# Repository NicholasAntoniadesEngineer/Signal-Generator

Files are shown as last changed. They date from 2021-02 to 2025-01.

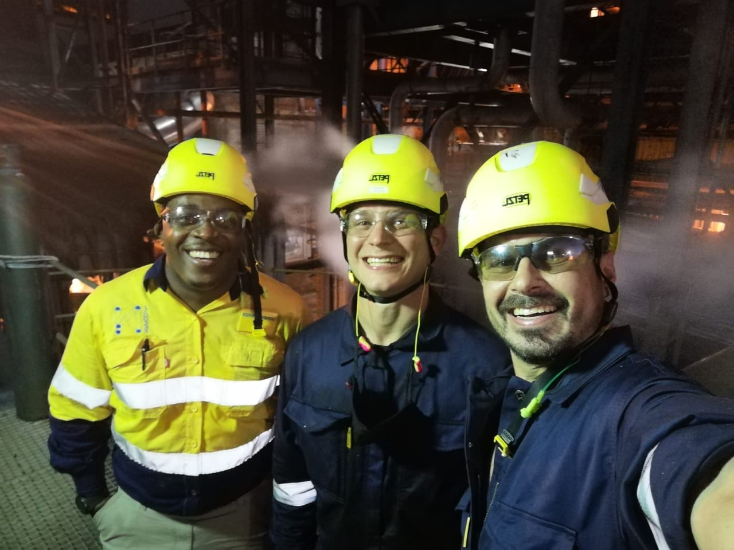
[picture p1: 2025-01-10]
pictures_and_videos/pictures/Installation crew 1.jpg

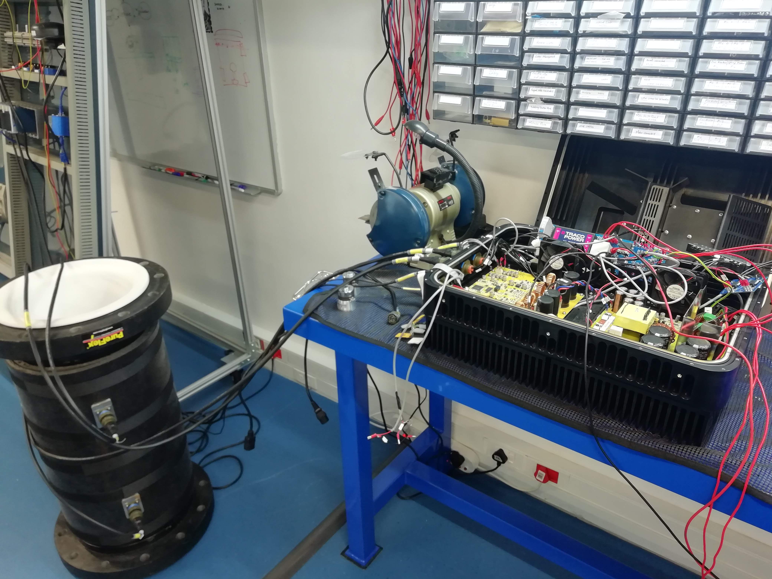
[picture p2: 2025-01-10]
pictures_and_videos/pictures/System Test.jpg

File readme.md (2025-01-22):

# Arbitrary Waveform Magnetic Field Generator (2020)

## Project Overview

This project focuses on developing an Arbitrary Waveform Generator (AWG) that allows the control of input signal frequency and amplitude through digital logic, interfacing with a CRIO (Compact Reconfigurable Input/Output) system. The system is designed to output a signal within the range of -2V to 2V peak-to-peak and supports a frequency range of 0-20kHz. The AWG is programmable via TTL or other logic interfaces.

This signal is then amplified and fed into a large coil to generate a magnetic field at the desired frequency and intensity.

## Industrial Application: Electromagnetic Scale Prevention

### Overview
The Arbitrary Waveform Generator was successfully deployed in an industrial sugar processing plant to combat scale formation in pipework. The system was integrated with a high-power amplifier to drive electromagnetic coils wrapped around critical pipe sections, implementing an innovative non-chemical scale prevention solution.

### System Configuration
- **Amplification Stage**: The AWG's output feeds into a high-power amplifier capable of driving large inductive loads
- **Electromagnetic Coils**: Custom-designed solenoid coils wrapped around pipe sections
- **Frequency Range**: Optimized to operate between 1-15 kHz for maximum effectiveness
- **Signal Characteristics**: Programmable waveforms with controlled frequency sweeps to target various mineral compositions

### Working Principle
The system generates precisely controlled electromagnetic fields that influence the crystallization process of scale-forming minerals. By affecting nucleation sites within the fluid

## Features

- **STM32 Microcontroller**: Implements the waveform generation using Direct Digital Synthesis (DDS).
- **Real-Time Operating System (RTOS)**: Ensures deterministic behavior for time-sensitive applications.
- **Programmable**: Supports control over frequency and amplitude via digital logic interfaces such as TTL.
- **Power Supply**: Operates with a wide input range and provides regulated outputs for the system.

## Waveform Generation Calculations

The AWG frequency generation is controlled through the following equations:

### 1. Prescaler (PSC):
PSC = ((Fclock / Ns) / (Fsine * (Period + 1))) - 1

Where:
- `Fclock` is the system clock frequency.
- `Ns` is the number of samples.
- `Fsine` is the desired sine wave frequency.
- `Period` is the period of the waveform.

### 2. Sine Wave Frequency (Fsine):
Fsine = (Fclock / Ns) / ((Period + 1) * (PSC + 1))

### Example Calculation:
Given the following values:
- `Fclock = 90MHz`
- `Ns = 100`
- `Period = 5`
- `PSC = 10`

You can calculate the sine wave frequency (`Fsine`) as:
Fsine = (90MHz / 100) / ((5 + 1) * (10 + 1)) = 13.636 kHz

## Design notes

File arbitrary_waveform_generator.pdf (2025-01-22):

# Arbitrary Waveform Generator

Nicholas Antoniades
2020

Table of Contents

1. (https://docs.google.com/document/d/1us7GVwpmYYnVgKDSI4ocPkmrK4ELYAW_x_JeFMqL49g/edit) Requirements
2. Design
3. PCB Configuration
4. Power Supply Validation
5. System Programming
6. System Test
7. Research

### Requirements

Attempting to find a black box solution that will allow the CRIO to control the input signal frequency and amplitude through some digital logic.

System Requirements:

1. An output achieving at least a -2V to 2V peak to peak output signal.
2. 0-20kHz frequency range.
3. Programmable via TTL or other logic.

PCB Requirements:

- USB DFU
- Power swich
- Level shifting circuitry
- DIP switch for boot mode settings
- DIP switch between power section and rest of circuit
- Power supply for +-5V
- Fuses
- Reset buttons
- LEDs
- ESD protection
- Reverse polarity protection
- SW with trace for debugging
- Temp sensor
- MAX485for RS485

### Design

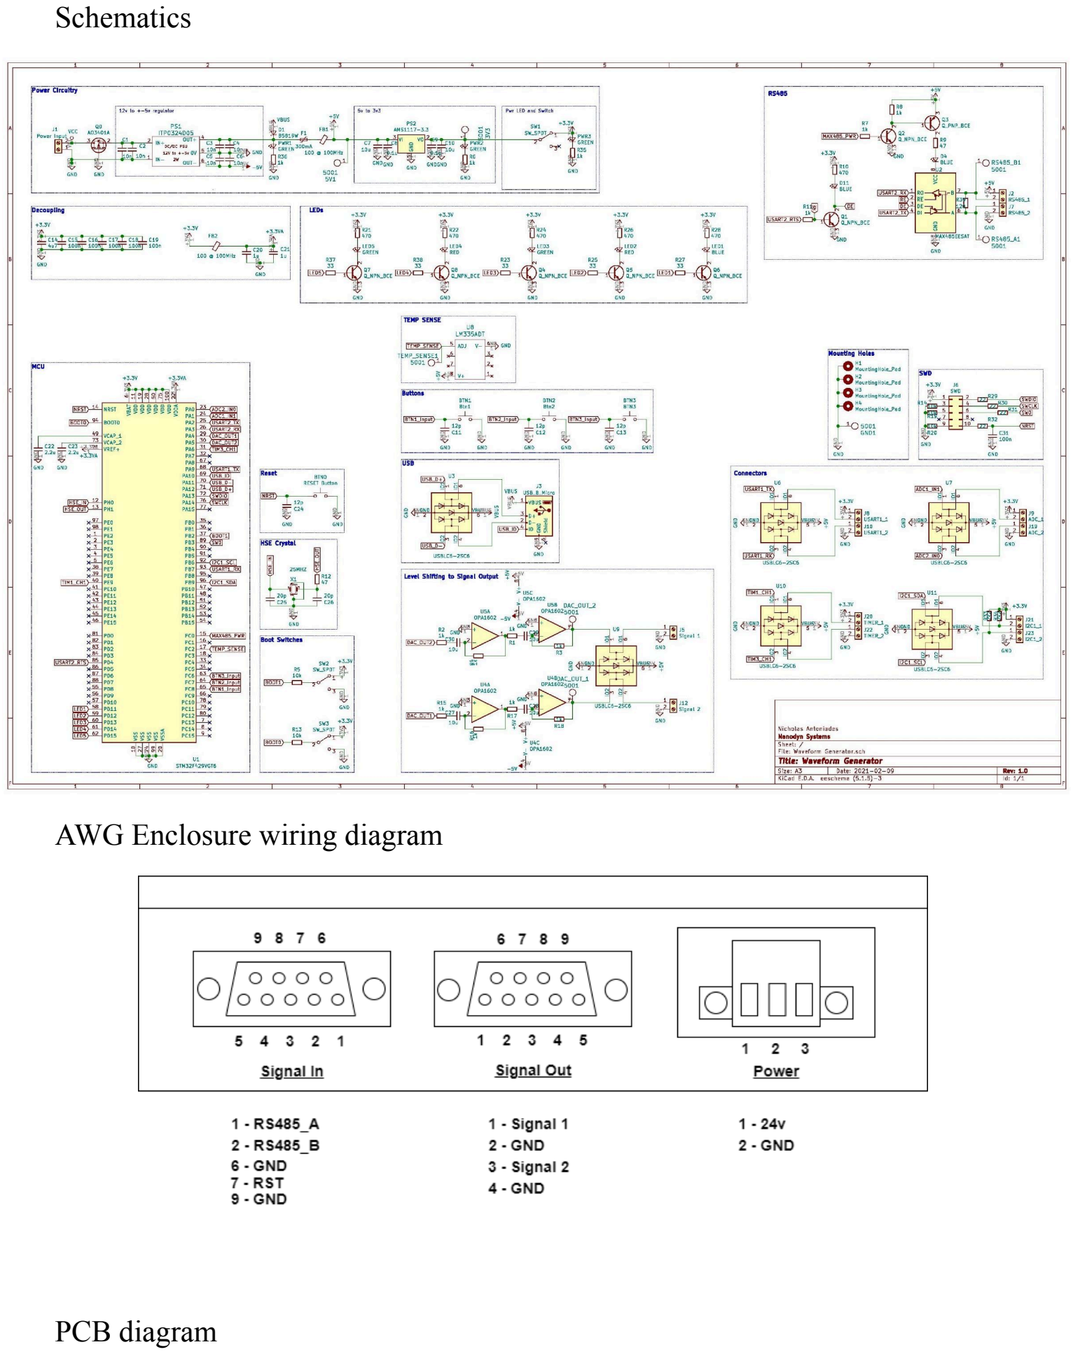
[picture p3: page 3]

Schematics

AWG Enclosure wiring diagram

PCB diagram

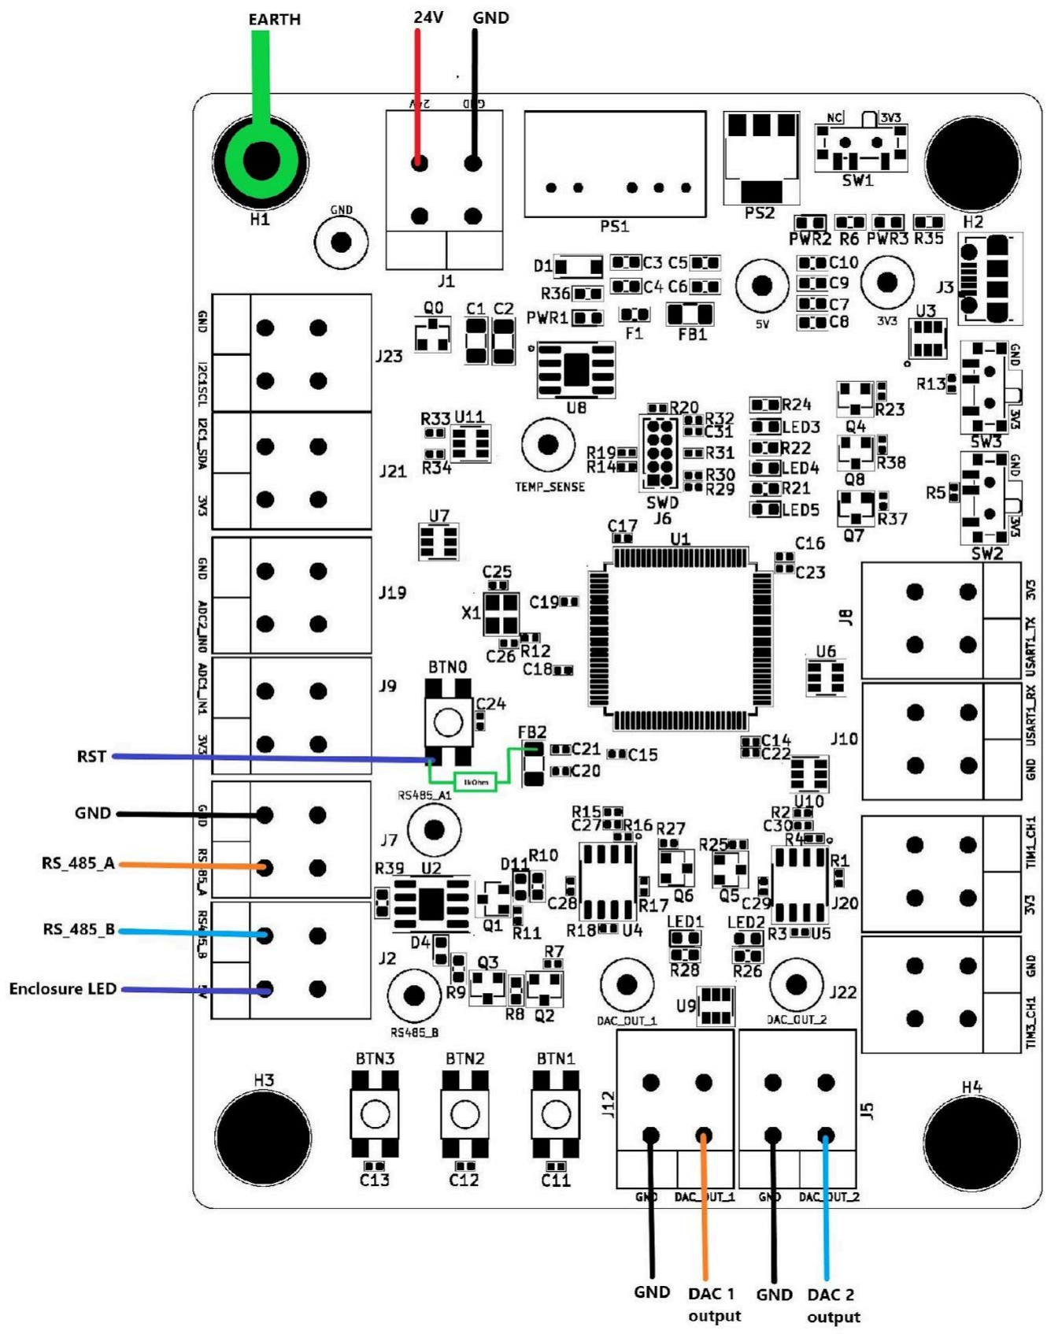
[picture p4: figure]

### PCB Configuration

Steps for setting up the PCB:

1. Add Fuse F1
2. Solder pull up resistor to NRST
3. Remove ESD protection U9. Bridge tracks as indicated
4. 10kOhm resistor was added as a pull-up resistor to bring the NRST pin to 3.3v
5. Removing LED D4 and bridging the pads as the voltage drop over the LED is such that the voltage over the MAX485 chip is too low.
6. Removing transistor Q1 and bridging its pads 1 and 2, then removing LED D11. This is so that DE and RE can be set at the same value. The original logic was so that they would be opposite values.
The 10kOhm pull-up resistor added can be seen in the figure below.
The ESD protection after the Op-Amp circuits were removed as the diode to the ground was clamping the circuit. Seen in the image below.
The inverting logic gate (The Npn diode) that was used to set the – pin and – pin which sets the MAX485 into transmit or receive mode was removed. This logic is not necessary as the pin is inverted already so both pins receive the same logic to switch between transmission and reception mode.

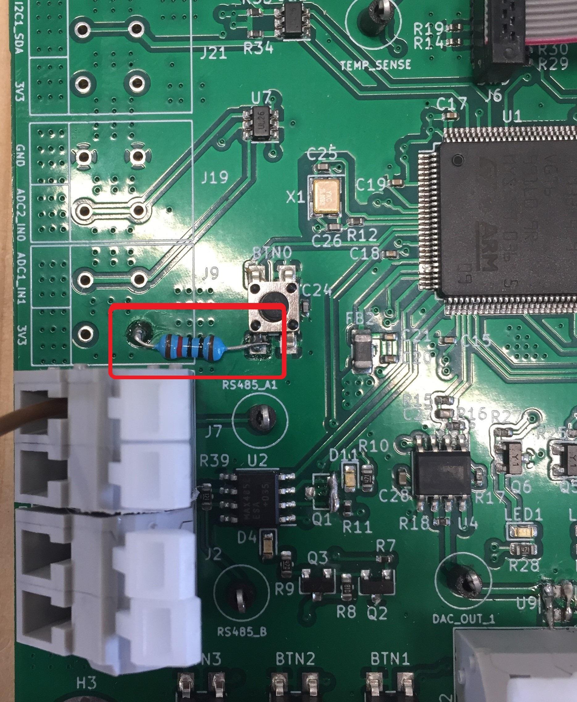
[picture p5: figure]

### Power supply validation

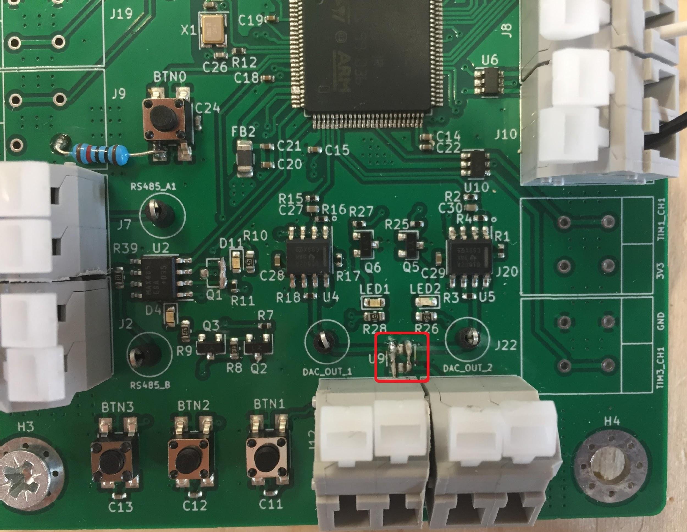
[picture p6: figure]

A 24V supply was connected to the 9V - 36V Input. +-5v and 3.3v were measured at the correct locations and STM MCU started up correctly and began to run the code.

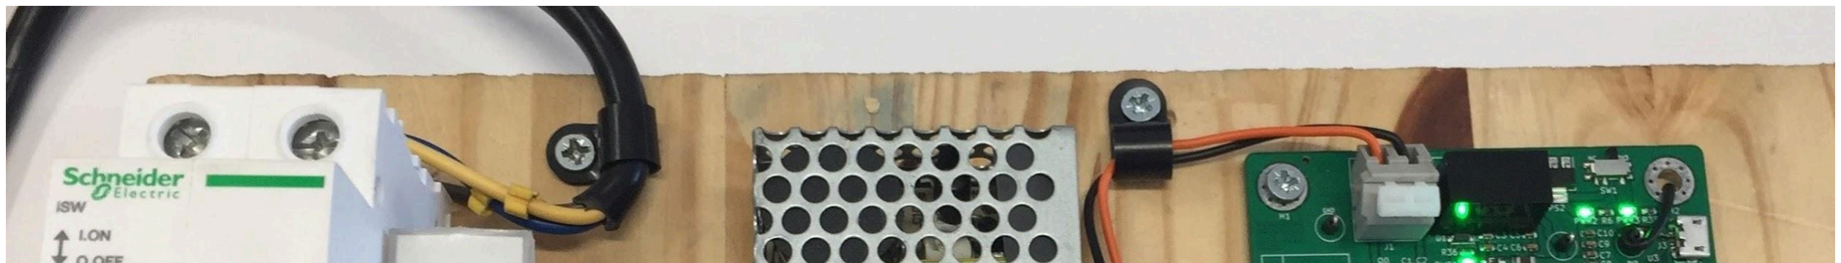
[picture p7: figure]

### System Programming

UART Programming of the AWG

The AWG was first programmed via the USB to serial interface
1. An external wire was soldered to a USB ID pin to access PA10
2. Boot0 switch(sw3) was set to 3v3 and the device was reset to enter bootloading mode.
3. Start STM32CubeProgrammer and select UART programming
4. Select erasing & programming.
5. Select the .elf file to be uploaded, this can be found in the Debug folder of the build files from the STM32CubeIDE.

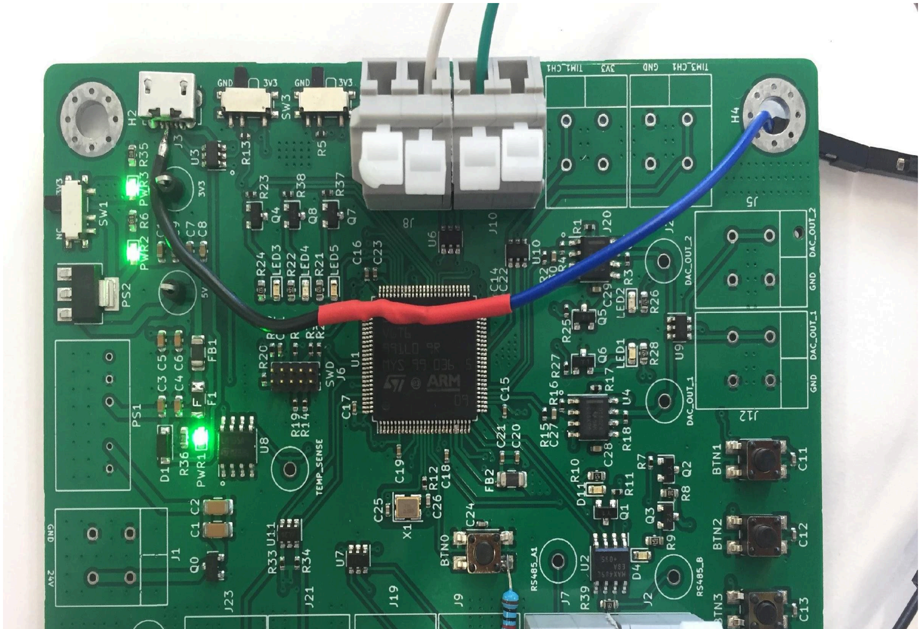
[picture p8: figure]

ST-Link V2 Programming of the AWG

1. Connect debugger and AWG PCB using the connector as seen in the figure below.
– | The footprint for the debugger on the AWG PCB is incorrect and inverted therefore the connector had to be manually wired to the correct orientation.
– | Add an extra wire from the ground of the debugger to the ground of the AWG PCB. Not seen in this image
2. Start STM32CubeProgrammer and select ST-Link programming
3. Select erasing & programming.
4. Select the .elf file to be uploaded, this can be found in the Debug folder of the build files from the STM32CubeIDE.

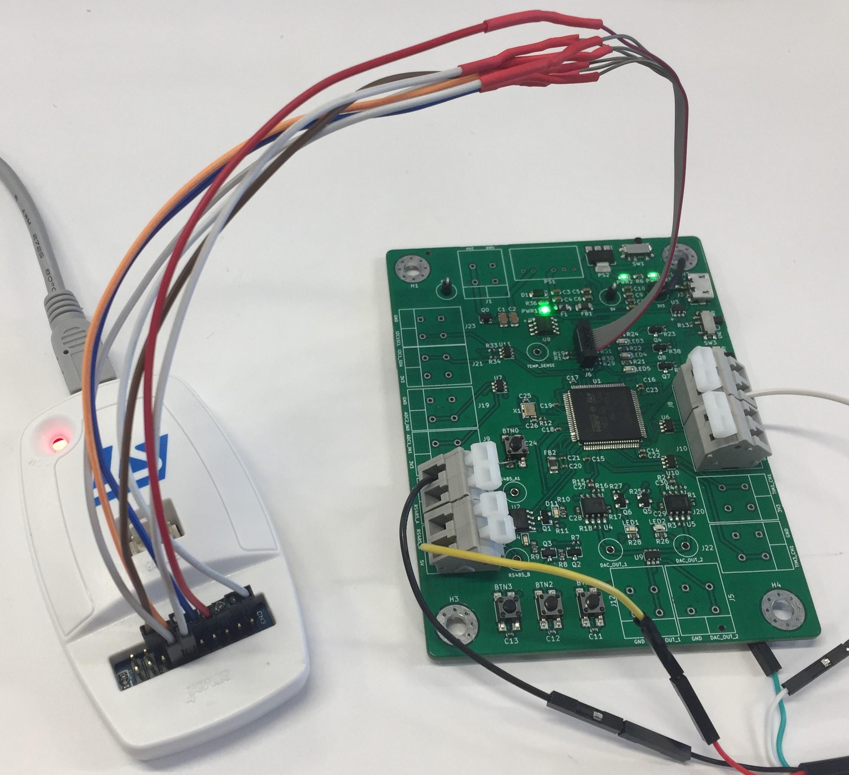
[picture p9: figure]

### System Test

The max output frequency is dependent on Ns, the number of samples that form one full period of the sine wave. For lower output frequencies a higher Ns can be used to increase the resolution of the signal. The following table indicates the appropriate ns value for a desired output frequency range. These are based on the STM32F429VGT6 used on the AWG. Based on the calculation:
PSC = - 1
There should be a function in the code that takes in the desired frequency and selects the appropriate Ns.
Other requirements for AWG:
1. The output signal must be scaled by o.5.
2. The output signal must be offset by 500.
3. DAC resolution = 4096
4. Fclock = 90 MHz
5. Period = 1.
6. PSC > 50

Setting up the RS485

1. Work on the correct response for uart
2. Set the MAX485 chip on

Waveform Generation Calculations:
PSC = - 1, Fsine = - 1, Fsine = = 13.636 kHz

Notes:
- When using op-amps it is important to consider the frequency limitations caused by the limited slew rate and bandwidth.
- Managing to get a working sine wave in the range of 0Hz and +- 50kHz.

### Research

Waveform Generation Calculations:

PSC = - 1, Fsine = - 1, Fsine = = 13.636 kHz
Notes:
- When using op-amps it is important to consider the frequency limitations caused by the limited slew rate and bandwidth.
- Managing to get a working sine wave in the range of 0Hz and +- 50kHz.
STM32 Nucleo 144 SWD Pinout
Using this pinout proved difficult and I was not able to programme the development board this way.

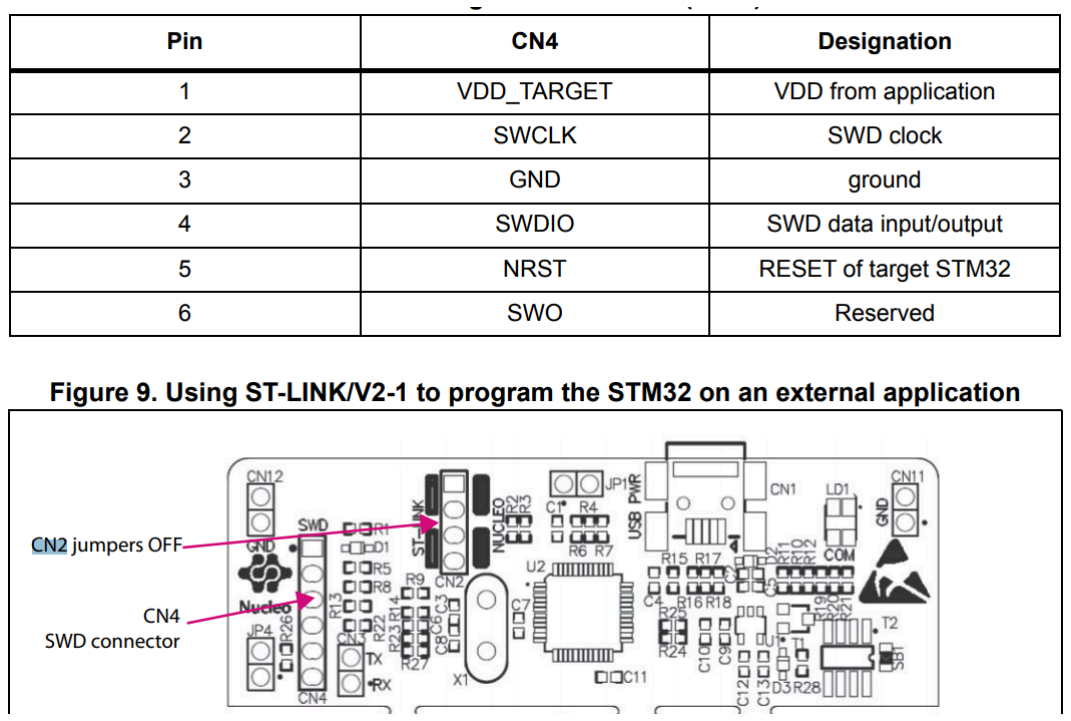
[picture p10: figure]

UART bootloader

Boot pin configurations: Refer to the chip reference manual for the correct configuration of pins Boot0 and Boot1 to put the device into the desired bootloader mode. For the STM32F439VGT6 the following pin configurations set the desired memory location to refer to for the boot mode.
USART bootloader protocol: Refer to AN2026 to activate the specific peripheral bootloader pins and settings. For the USART1 bootloader protocol commands and process refer to AN3155.
All communication from the programming tool to the device is verified by:
1. Checksum: received blocks of data bytes are XOR-ed. A byte containing the computed XOR of all previous bytes is added to the end of each communication (checksum byte). By XOR-ing all received bytes, data plus checksum, the result at the end of the packet must be 0x00.
2. For each command, the host sends a byte and its complement (XOR = 0x00).
3. UART: 1 start bit, even parity and 1 stop bit.
4. Each packet is either accepted (ACK answer) or discarded (NACK answer):
– | ACK = 0x79
– | NACK = 0x1F
UART message protocol

8 bytes message structure:
|<|(60/3C) : Start of message byte. |ADDR|() : Device Address byte. |CMD|() : Command byte. |DATA1| : Data byte 1. |DATA2| : Data byte 2. |DATA3| : Data byte 3. |DATA4| : Data byte 4. |>|(62/3E) : End of message byte.
List of commands from CRIO to STM:
1. On/off command.
2. Change - the frequency of DAC channel 1.
3. Change - the frequency of DAC channel 2.
4. Change - the amplitude of DAC channel 1.
5. Change - the amplitude of DAC channel 2.
6. Request - Voltage and Current measurement of channel 1 output.
7. Request - Voltage and Current measurement of channel 2 output.
8. Request - Temperature sensor 1 and 2 output.
9. Acknowledge message received.
10. Bad message received.
11. Request current system state.
List of messages from STM to CRIO:
1. Return - the frequency of DAC channel 1.
2. Return - the frequency of DAC channel 2.
3. Return - the amplitude of DAC channel 1.
4. Return - the amplitude of DAC channel 2.

5. Return - Voltage and Current measurement of channel 1 output.
6. Return - Voltage and Current measurement of channel 2 output.
7. Return - Temperature sensors 1 and 2 output.
8. Acknowledge message received.
9. Bad message received.
10. Low power mode.
List of Bootloader commands This is a snippet from AN3155. Each command that is sent through to the STM must be sent with its compliment.
- The STM will return with a “79” to acknowledge a correct message.

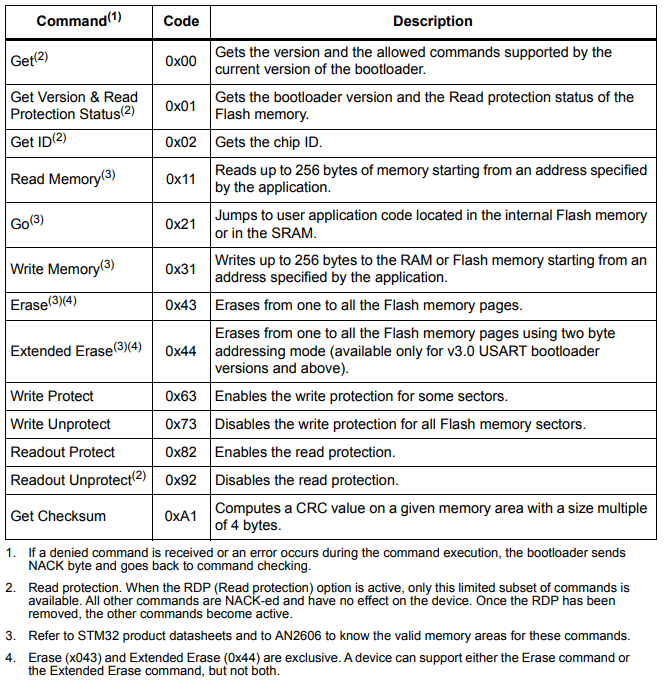
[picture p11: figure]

Once the system memory boot mode is entered and the STM32 has been configured:
1. The DFU command “7F 00”, No compliment needed
2. The GET command “00 FF”
3. The GO command “21 DE”

– | Send, the start address, this is usually 0x8000000, wait for ACK
– | Might require a checksum to be sent with this address, AN315
4. The EXTENDED ERASE command “44 BB” (This seems to work inconsistently).
– | First, send the READ PROTECT command “82 7D”
– | Then send the READ UNPROTECT “92 6D”
– | The WRITE UNPROTECT command “73 8C”
– | Then send EXTENDED ERASE COMMAND “44 BB”
5. The WRITE MEMORY command “31 CE”
– | Send, 31 CE, wait for ACK
– | Send, 08 00 00 00 08, the start address which is usually 0x08000000 and the CRC, wait for ACK
– | Send, the number of bytes to be written (1 byte), the data (N+1 bytes), the checksum, wait for ACK
| • Checksum byte: XOR (N, N+1 data bytes)
| • N+1 must be a multiple of 4
6. The WRITE PROTECT command “63 63”
7. The WRITE UNPROTECT command “73 8C”
8. The READ PROTECT command “82 7D”
9. The READ UNPROTECT command “92 6D”

### Software changes

Problem
The max485 chip is physically connected to UART2 Tx and Rx pins. UART2 uses the same DMA channels as the DAC 1 and 2 outputs. So using the DMA method for receiving data on the UART2 RX line won’t work.
Solution : - Using the UART interrupt (IT) method to handle the received messages. - Using the UART polling method for sending messages

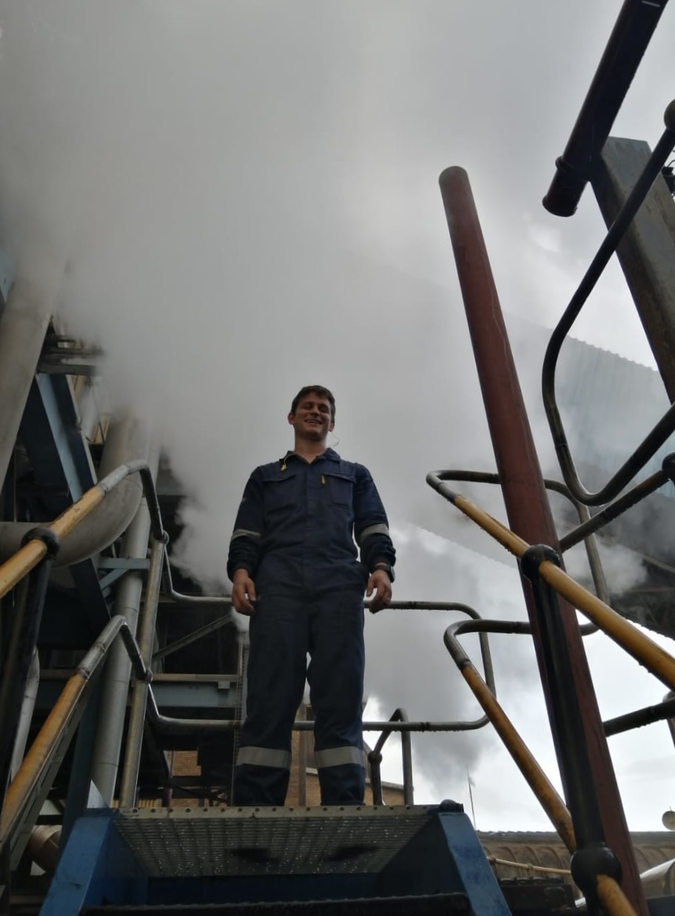
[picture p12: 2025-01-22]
pictures_and_videos/pictures/Me.jpg

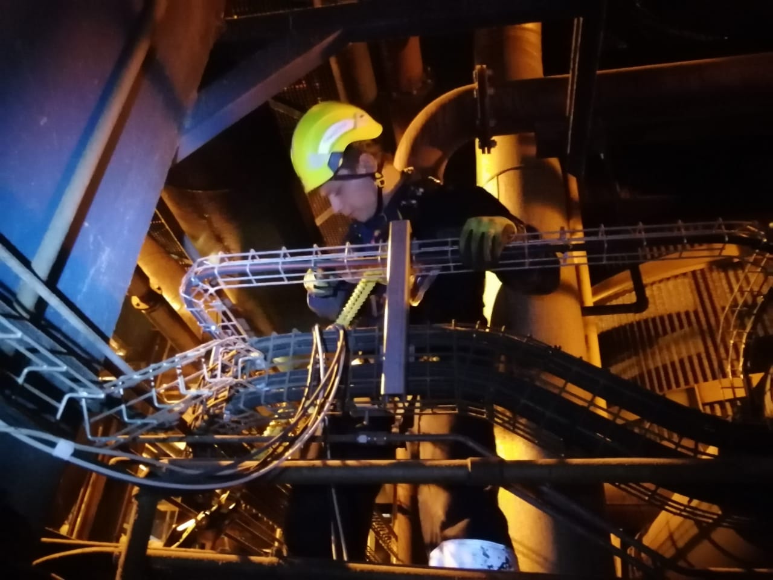
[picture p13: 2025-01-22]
pictures_and_videos/pictures/me_1.jpg

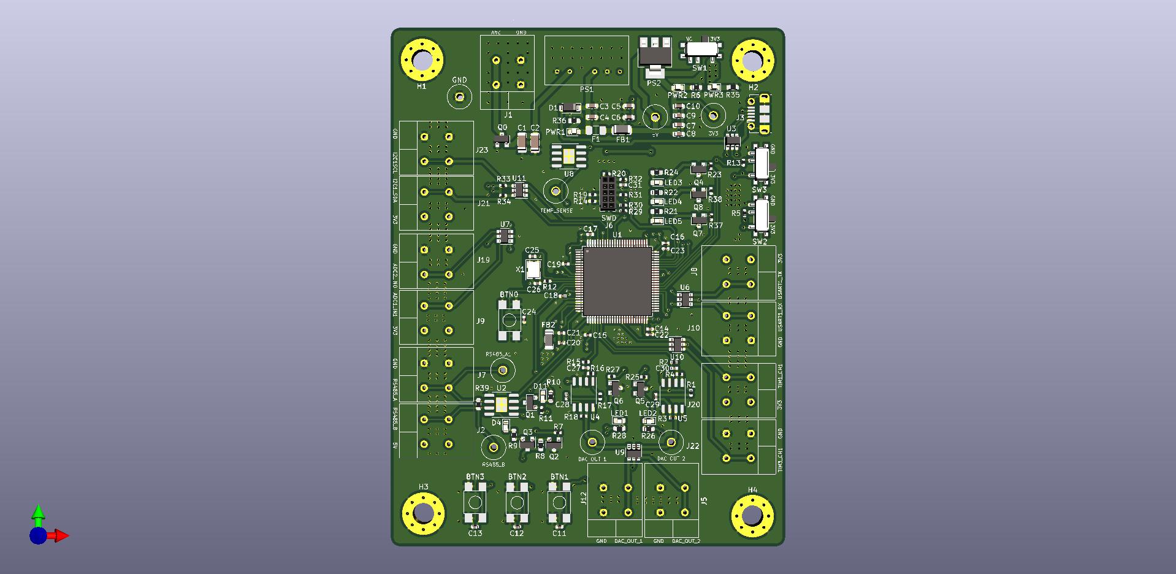
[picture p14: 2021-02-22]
pictures_and_videos/pictures/Arbitrary Waveform Generator Render.jpg

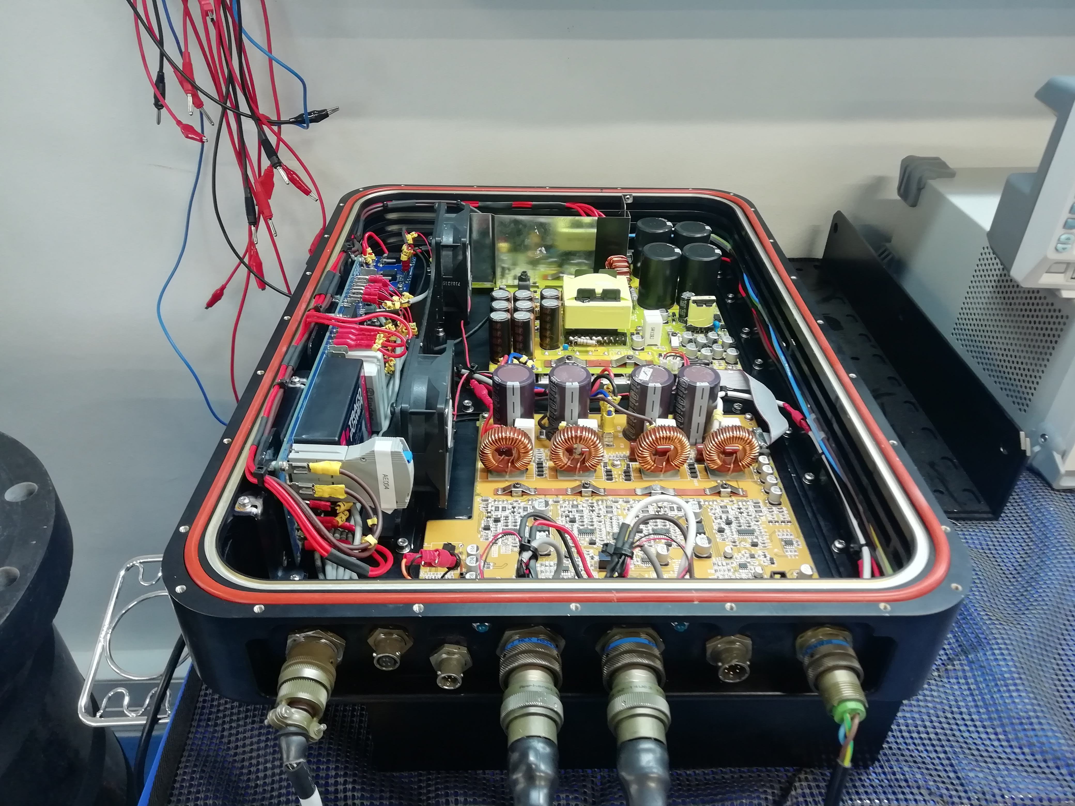
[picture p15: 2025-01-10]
pictures_and_videos/pictures/Signal Amplifier.jpg

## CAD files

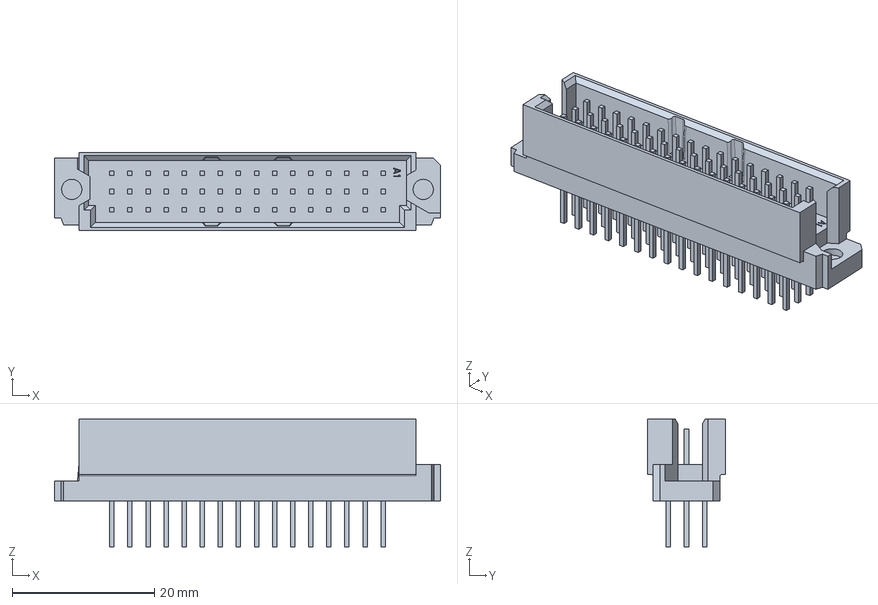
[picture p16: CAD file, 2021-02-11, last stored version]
PCB/Reference/Aether Design/CAD/c-650918-5-m-3d.stp
54.2 x 11.0 x 18.0 mm

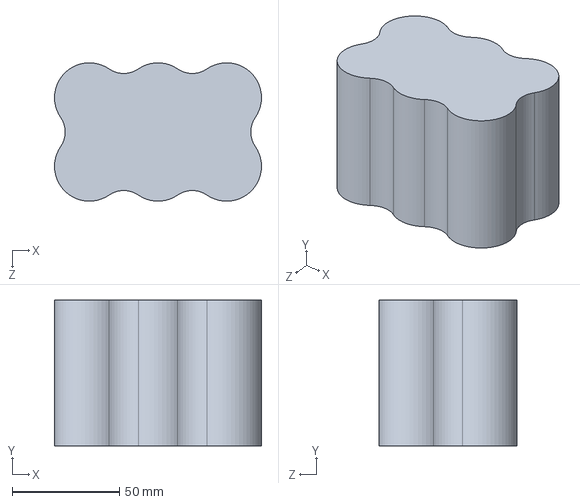
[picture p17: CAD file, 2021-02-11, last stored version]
PCB/Reference/Aether Design/Hardware Specifications/Battery/Battery_3x2_5000mAh.STEP
96.5 x 68.0 x 64.5 mm

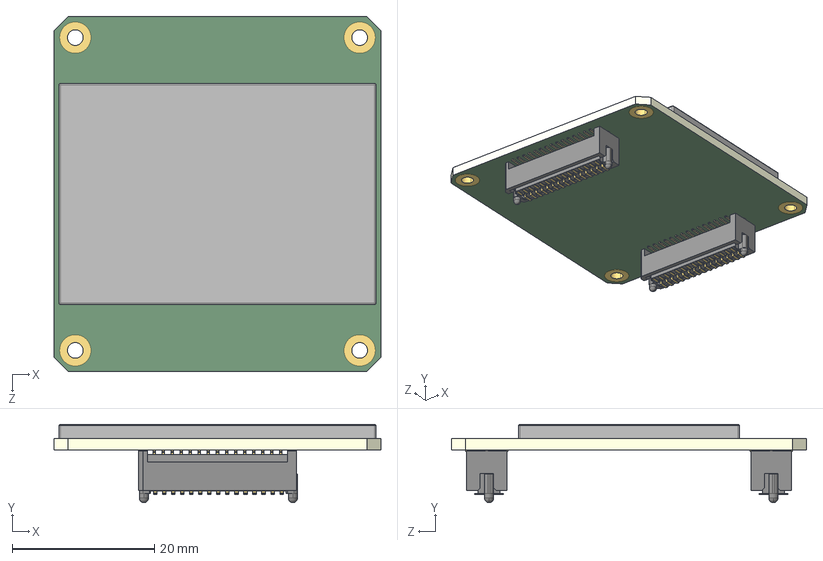
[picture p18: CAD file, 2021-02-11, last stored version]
PCB/Reference/Aether Design/Hardware Specifications/MCU Stacker/MCUStacker_Preliminary.STEP
46.0 x 11.0 x 50.0 mm
SFM-115-02-L-D-A-K-TR x 2
TFM-115-02-L-D-A-K-TR x 2
Part2^MCUStacker_Dummy

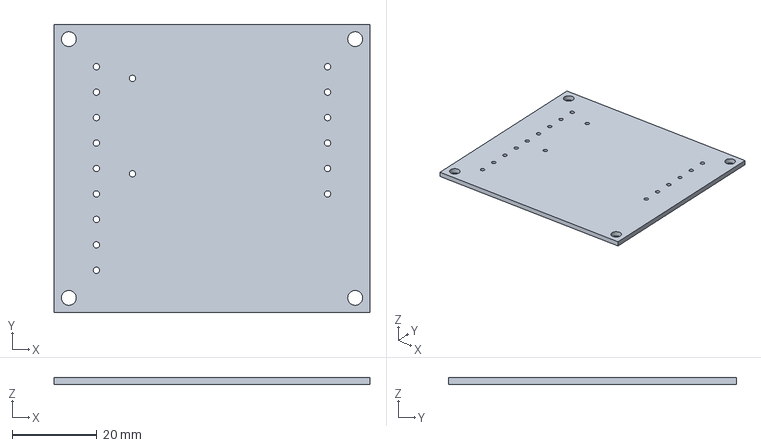
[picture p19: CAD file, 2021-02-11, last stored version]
PCB/Reference/Renard/KiCad/Amp_Input_Filter/Amp_Input_Filter.step
74.5 x 68.0 x 1.60 mm

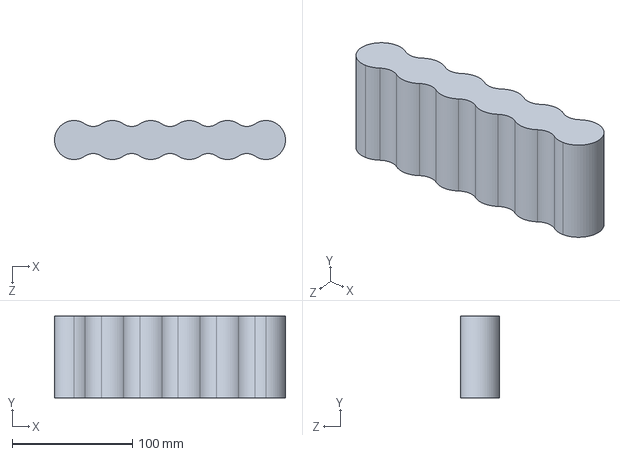
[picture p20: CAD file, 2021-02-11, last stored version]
PCB/Reference/Aether Design/Hardware Specifications/Battery/Battery_6x1_5000mAh.STEP
192.5 x 68.0 x 32.5 mm

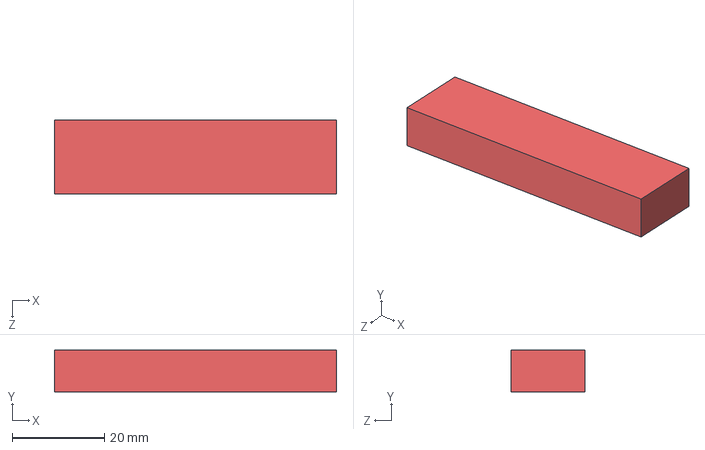
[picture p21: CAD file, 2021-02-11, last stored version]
PCB/Reference/Aether Design/Hardware Specifications/Battery/HCX-D103.STEP
61.0 x 9.00 x 16.0 mm

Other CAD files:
PCB/Reference/Aether Design/CAD/c-650918-5-m-3d.SLDPRT

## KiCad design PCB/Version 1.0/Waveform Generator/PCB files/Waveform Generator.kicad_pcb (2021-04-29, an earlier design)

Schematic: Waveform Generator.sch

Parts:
3V3, 5V1: 5001; 5001 Test Point
BTN0: RESET Button; TS-1109S-B-B
BTN1: Btn1; TS-1109S-B-B
BTN2: Btn2; TS-1109S-B-B
BTN3: BTN3; TS-1109S-B-B
C1, C2: 10n; C_1206_3216Metric
C3, C4, C5, C6: 10n; C_0603_1608Metric
C7, C10: 10u; C_0603_1608Metric
C8, C9: 0.1u; C_0603_1608Metric
C11, C12, C13, C24: 12p; C_0402_1005Metric
C14: 4u7; C_0402_1005Metric
C15, C16, C17, C18, C19, C31: 100n; C_0402_1005Metric
C20, C21: 1u; C_0402_1005Metric
C22, C23: 2.2u; C_0402_1005Metric
C25, C26: 20p; C_0402_1005Metric
C27, C28, C29, C30: 10u; C_0402_1005Metric
D1: B5819W; D_SOD-123
D4, D11: BLUE; LED_0603_1608Metric
DAC_OUT_1, DAC_OUT_2: 5001; 5001 Test Point
F1: 300mA; Fuse_0603_1608Metric
FB1, FB2: 100 @ 100MHz; L_1206_3216Metric
GND1: 5001; 5001 Test Point
H1, H2, H3, H4: MountingHole_Pad; MountingHole_4.3mm_M4_Pad_Via
J1: Power input; 5mm Pitch, 2 Way Terminal Block
J2: RS485_1; 5mm Pitch, 2 Way Terminal Block
J3: USB_B_Micro; USB_Micro-B_Molex-105017-0001
J5: Signal 1; 5mm Pitch, 2 Way Terminal Block
J6: SWD; PinSocket_2x05_P1.27mm_Vertical
J7: RS485_2; 5mm Pitch, 2 Way Terminal Block
J8: USART1_1; 5mm Pitch, 2 Way Terminal Block
J9: ADC_1; 5mm Pitch, 2 Way Terminal Block
J10: USART1_2; 5mm Pitch, 2 Way Terminal Block
J12: Signal 2; 5mm Pitch, 2 Way Terminal Block
J19: ADC_2; 5mm Pitch, 2 Way Terminal Block
J20: TIMER_1; 5mm Pitch, 2 Way Terminal Block
J21: I2C1_1; 5mm Pitch, 2 Way Terminal Block
J22: TIMER_2; 5mm Pitch, 2 Way Terminal Block
J23: I2C1_2; 5mm Pitch, 2 Way Terminal Block
LED1: BLUE; LED_0603_1608Metric
LED2, LED4: RED; LED_0603_1608Metric
LED3, LED5: GREEN; LED_0603_1608Metric
PS1: ITP0324D05; ITP0312D05
PS2: AMS1117-3.3; SOT-223-3_TabPin2
PWR1, PWR2, PWR3: GREEN; LED_0603_1608Metric
Q0: AO3401A; SOT-23
Q1, Q2, Q4, Q5, Q6, Q7, Q8: Q_NPN_BCE; SOT-23
Q3: Q_PNP_BCE; SOT-23
R1, R2, R3, R4, R7, R11, R15, R16, R17, R18: 1k; R_0402_1005Metric
R5, R13, R14, R19, R20: 10k; R_0402_1005Metric
R6, R8, R35, R36: 1k; R_0603_1608Metric
R9: 47; R_0603_1608Metric
R10, R21, R22, R24, R26, R28: 470; R_0603_1608Metric
R12: 47; R_0402_1005Metric
R23, R25, R27, R37, R38: 33; R_0402_1005Metric
R29, R30, R31, R32: 22; R_0402_1005Metric
R33, R34: 2k2; R_0402_1005Metric
R39: 120; R_0603_1608Metric
RS485_A1, RS485_B1: 5001; 5001 Test Point
SW1, SW2, SW3: SW_SPDT; SW_SPDT_PCM12
TEMP_SENSE1: 5001; 5001 Test Point
U1: STM32F429VGT6; LQFP-100_14x14mm_P0.5mm
U2: MAX485EESAT; SOIC-8-1EP_3.9x4.9mm_P1.27mm_EP2.29x3mm
U3, U6, U7, U9, U10, U11: USBLC6-2SC6; SOT-23-6
U4, U5: OPA1602; SOP-8_3.9x4.9mm_P1.27mm
U8: LM335ADT; SOIC-8-1EP_3.9x4.9mm_P1.27mm_EP2.29x3mm
X1: 25MHZ; Crystal_SMD_3225-4Pin_3.2x2.5mm

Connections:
+3.3VA: C20.1, C21.2, FB2.2, U1.21 (VREF+), U1.22 (VDDA)
+3V3: C14.1, C15.1, C16.1, C17.1, C18.1, C19.1, FB2.1, J6.1, J8.1, J9.1, J20.1, J21.1, PWR3.2 (A), R10.1, R21.1, R22.1, R24.1, R26.1, R28.1, R33.2, R34.2, SW1.1 (A), SW2.1 (A), SW3.1 (A), U1.6 (VBAT), U1.11 (VDD), U1.19 (VDD), U1.28 (VDD), U1.50 (VDD), U1.75 (VDD), U1.100 (VDD)
+5V: C7.1, C8.1, FB1.2, J2.1, PS2.3 (VI), Q3.3 (E), R8.1, U4.8 (V+), U5.8 (V+), U6.5 (VBUS), U7.5 (VBUS), U8.8, U9.5 (VBUS), U10.5 (VBUS), U11.5 (VBUS); also elsewhere on the board
-5V: C5.2, C6.2, PS1.6, U4.4 (V-), U5.4 (V-)
ADC1_IN1: U1.24 (PA1), U7.1 (IO1)
ADC2_IN0: U1.23 (PA0), U7.3 (IO2)
BOOT0: R13.2, U1.94 (BOOT0)
BOOT1: R5.2, U1.37 (PB2)
BTN1_Input: BTN1.1, C11.2, U1.65 (PC8)
BTN2_Input: BTN2.1, C12.2, U1.64 (PC7)
BTN3_Input: BTN3.1, C13.2, U1.63 (PC6)
DAC_OUT1: R15.2, U1.29 (PA4)
DAC_OUT2: R2.2, U1.30 (PA5)
DE: D11.1 (K), Q1.2 (C), U2.3 (DE)
GND: BTN0.2, BTN1.2, BTN2.2, BTN3.2, C1.2, C2.1, C3.2, C4.2, C5.1, C6.1, C7.2, C8.2, C9.2, C10.2, C11.1, C12.1, C13.1, C14.2, C15.2, C16.2, C17.2, C18.2, C19.2, C20.2, C21.1, C22.2, C23.2, C24.1, C25.1, C26.1, C31.2, H1.1, H2.1, H3.1, H4.1, J1.1, J3.5 (GND), J5.2, J7.2, J10.2, J12.2, J19.2, J22.2, J23.2, PS1.1, PS1.5, Q0.1 (G), Q1.3 (E), Q2.3 (E), Q4.3 (E), Q5.3 (E), Q6.3 (E), Q7.3 (E), Q8.3 (E), R6.2, R14.2, R19.2, R20.2, R35.2, R36.2, SW2.3 (C), SW3.3 (C), U1.10 (VSS), U1.20 (VSSA), U1.27 (VSS), U1.74 (VSS), U1.99 (VSS), U2.5 (GND), U3.2 (GND), U4.3 (+), U4.5 (+), U5.3 (+), U5.5 (+), U6.2 (GND), U7.2 (GND), U8.4, U9.2 (GND), U10.2 (GND), U11.2 (GND), X1.2, X1.4; also elsewhere on the board
HSE_IN: C25.2, U1.12 (PH0), X1.1
HSE_OUT: R12.1, U1.13 (PH1)
I2C1_SCL: U1.92 (PB6), U11.3 (IO2)
I2C1_SDA: U1.96 (PB9), U11.1 (IO1)
LED1: R27.2, U1.58 (PD11)
LED2: R25.2, U1.59 (PD12)
LED3: R23.2, U1.60 (PD13)
LED4: R38.2, U1.61 (PD14)
LED5: R37.2, U1.62 (PD15)
MAX485_PWR: R7.2, U1.15 (PC0)
NRST: BTN0.1, C24.2, C31.1, R32.1, U1.14 (NRST)
unnamed: 3V3.1, C9.1, C10.1, PS2.2 (VO), PWR2.2 (A), SW1.2 (B)
unnamed: C1.1, C2.2, PS1.2, Q0.2 (S)
unnamed: C3.1, C4.1, D1.1 (K), F1.2, PS1.4, PWR1.2 (A)
unnamed: C22.1, U1.49 (VCAP_1)
unnamed: C23.1, U1.73 (VCAP_2)
unnamed: C26.2, R12.2, X1.3
unnamed: C27.1, R15.1
unnamed: C27.2, R16.1, U4.2 (-)
unnamed: C28.1, R17.1
unnamed: C28.2, R18.2, U4.6 (-)
unnamed: C29.1, R1.1
unnamed: C29.2, R3.2, U5.6 (-)
unnamed: C30.1, R2.1
unnamed: C30.2, R4.1, U5.2 (-)
unnamed: D4.1 (K), U2.8 (VCC)
unnamed: D4.2 (A), R9.2
unnamed: D11.2 (A), R10.2
unnamed: DAC_OUT_1.1, R18.1, U4.7, U9.3 (IO2)
unnamed: DAC_OUT_2.1, R3.1, U5.7, U9.1 (IO1)
unnamed: F1.1, FB1.1
unnamed 46: J2.2, R39.1, U2.7 (B); also elsewhere on the board
unnamed: J3.2 (D-), U3.4 (IO2)
unnamed: J3.3 (D+), U3.6 (IO1)
unnamed: J5.1, U9.6 (IO1)
unnamed: J6.2, R29.2
unnamed: J6.3, R14.1
unnamed: J6.4, R30.2
unnamed: J6.5, R19.1
unnamed: J6.6, R31.2
unnamed: J6.9, R20.1
unnamed: J6.10, R32.2
unnamed: J7.1, R39.2, RS485_A1.1, U2.6 (A)
unnamed: J8.2, U6.6 (IO1)
unnamed: J9.2, U7.6 (IO1)
unnamed: J10.1, U6.4 (IO2)
unnamed: J12.1, U9.4 (IO2)
unnamed: J19.1, U7.4 (IO2)
unnamed: J20.2, U10.6 (IO1)
unnamed: J21.2, R34.1, U11.6 (IO1)
unnamed: J22.1, U10.4 (IO2)
unnamed: J23.1, R33.1, U11.4 (IO2)
unnamed: LED1.1 (K), Q6.2 (C)
unnamed: LED1.2 (A), R28.2
unnamed: LED2.1 (K), Q5.2 (C)
unnamed: LED2.2 (A), R26.2
unnamed: LED3.1 (K), Q4.2 (C)
unnamed: LED3.2 (A), R24.2
unnamed: LED4.1 (K), Q8.2 (C)
unnamed: LED4.2 (A), R22.2
unnamed: LED5.1 (K), Q7.2 (C)
unnamed: LED5.2 (A), R21.2
unnamed: PWR1.1 (K), R36.1
unnamed: PWR2.1 (K), R6.1
unnamed: PWR3.1 (K), R35.1
unnamed: Q2.1 (B), R7.1
unnamed: Q2.2 (C), Q3.1 (B), R8.2
unnamed: Q3.2 (C), R9.1
unnamed: Q4.1 (B), R23.1
unnamed: Q5.1 (B), R25.1
unnamed: Q6.1 (B), R27.1
unnamed: Q7.1 (B), R37.1
unnamed: Q8.1 (B), R38.1
unnamed: R1.2, R4.2, U5.1
unnamed: R5.1, SW2.2 (B)
unnamed: R13.1, SW3.2 (B)
unnamed: R16.2, R17.2, U4.1
RE: Q1.1 (B), R11.1, U2.2 (~RE)
SW0: R31.1, U1.89 (PB3)
SWCLK: R30.1, U1.76 (PA14)
SWDIO: R29.1, U1.72 (PA13)
TEMP_SENSE: U1.17 (PC2), U8.5; also elsewhere on the board
TIM1_CH1: U1.40 (PE9), U10.1 (IO1)
TIM3_CH1: U1.31 (PA6), U10.3 (IO2)
USART1_RX: U1.93 (PB7), U6.3 (IO2)
USART1_TX: U1.68 (PA9), U6.1 (IO1)
USART2_RTS: R11.2, U1.85 (PD4)
USART2_RX: U1.26 (PA3), U2.1 (RO)
USART2_TX: U1.25 (PA2), U2.4 (DI)
USB_D+: U1.71 (PA12), U3.1 (IO1)
USB_D-: U1.70 (PA11), U3.3 (IO2)
USB_ID: J3.4 (ID), U1.69 (PA10)
VBUS: D1.2 (A), J3.1 (VBUS), U3.5 (VBUS)
VCC: J1.2, Q0.3 (D)

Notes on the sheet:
5v to 3v3
Pwr LED and Switch
HSE Crystal
Boot Switches
Reset
MCU
Decoupling
Connectors
Buttons
SWD
Mounting Holes
12v to +-5v regulator
RS485
LEDs
Level Shifting to Signal Output
USB
Power Circuitry
TEMP SENSE

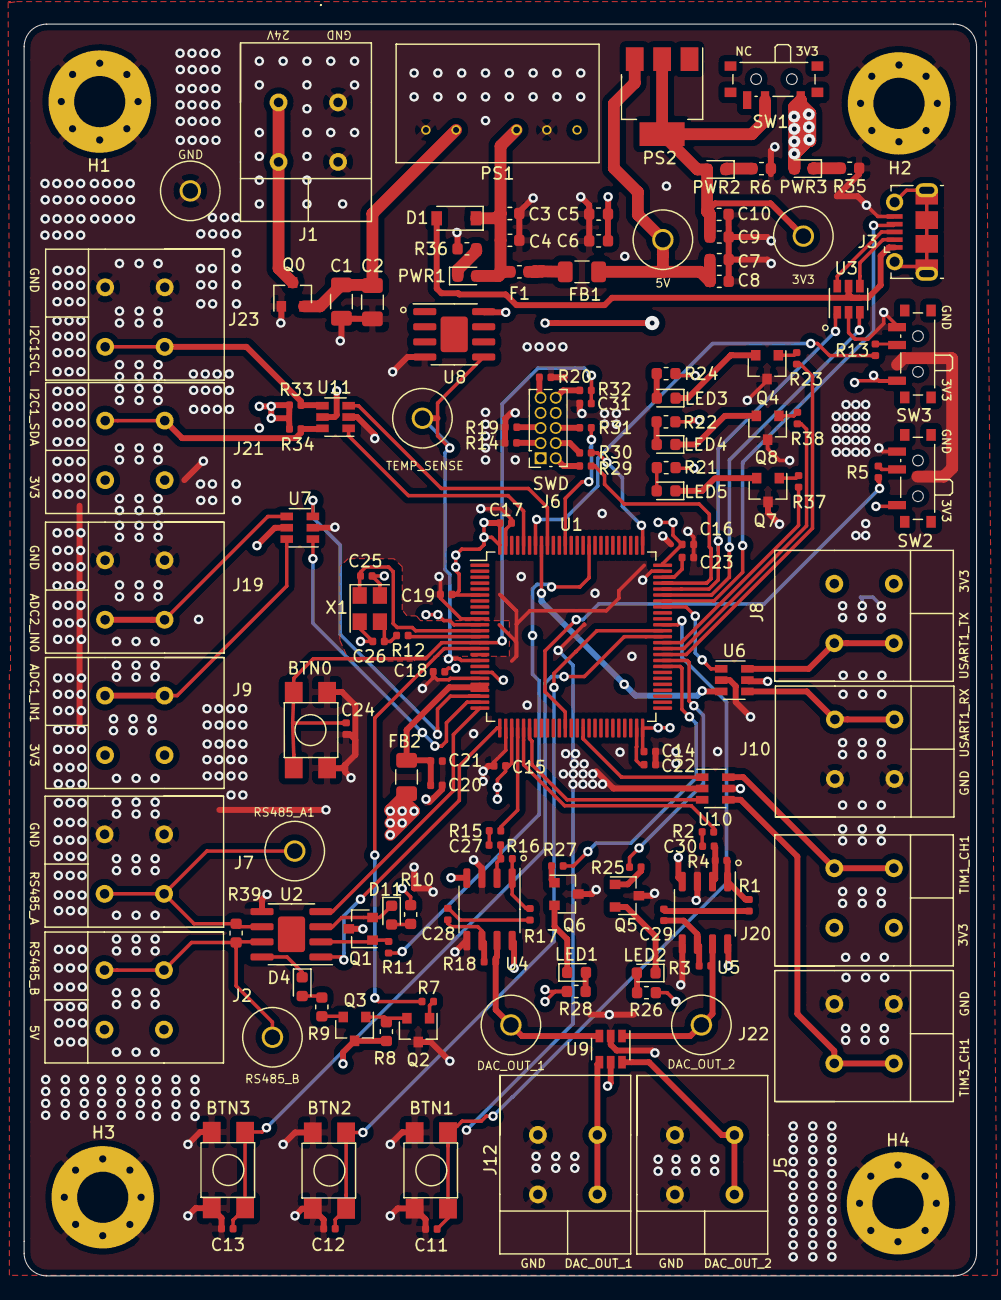
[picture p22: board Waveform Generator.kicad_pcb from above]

Board: 4 copper layers, 80.0 x 105.2 mm, 141 parts (0 on the bottom side), 109 nets.

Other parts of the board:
5V: 5001; 5001 Test Point
GND: 5001; 5001 Test Point
RS485_B: 5001; 5001 Test Point
TEMP_SENSE: 5001; 5001 Test Point

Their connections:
+5V: 5V.1; also elsewhere on the board
GND: GND.1; also elsewhere on the board
unnamed 46: RS485_B.1; also elsewhere on the board
TEMP_SENSE: TEMP_SENSE.1; also elsewhere on the board

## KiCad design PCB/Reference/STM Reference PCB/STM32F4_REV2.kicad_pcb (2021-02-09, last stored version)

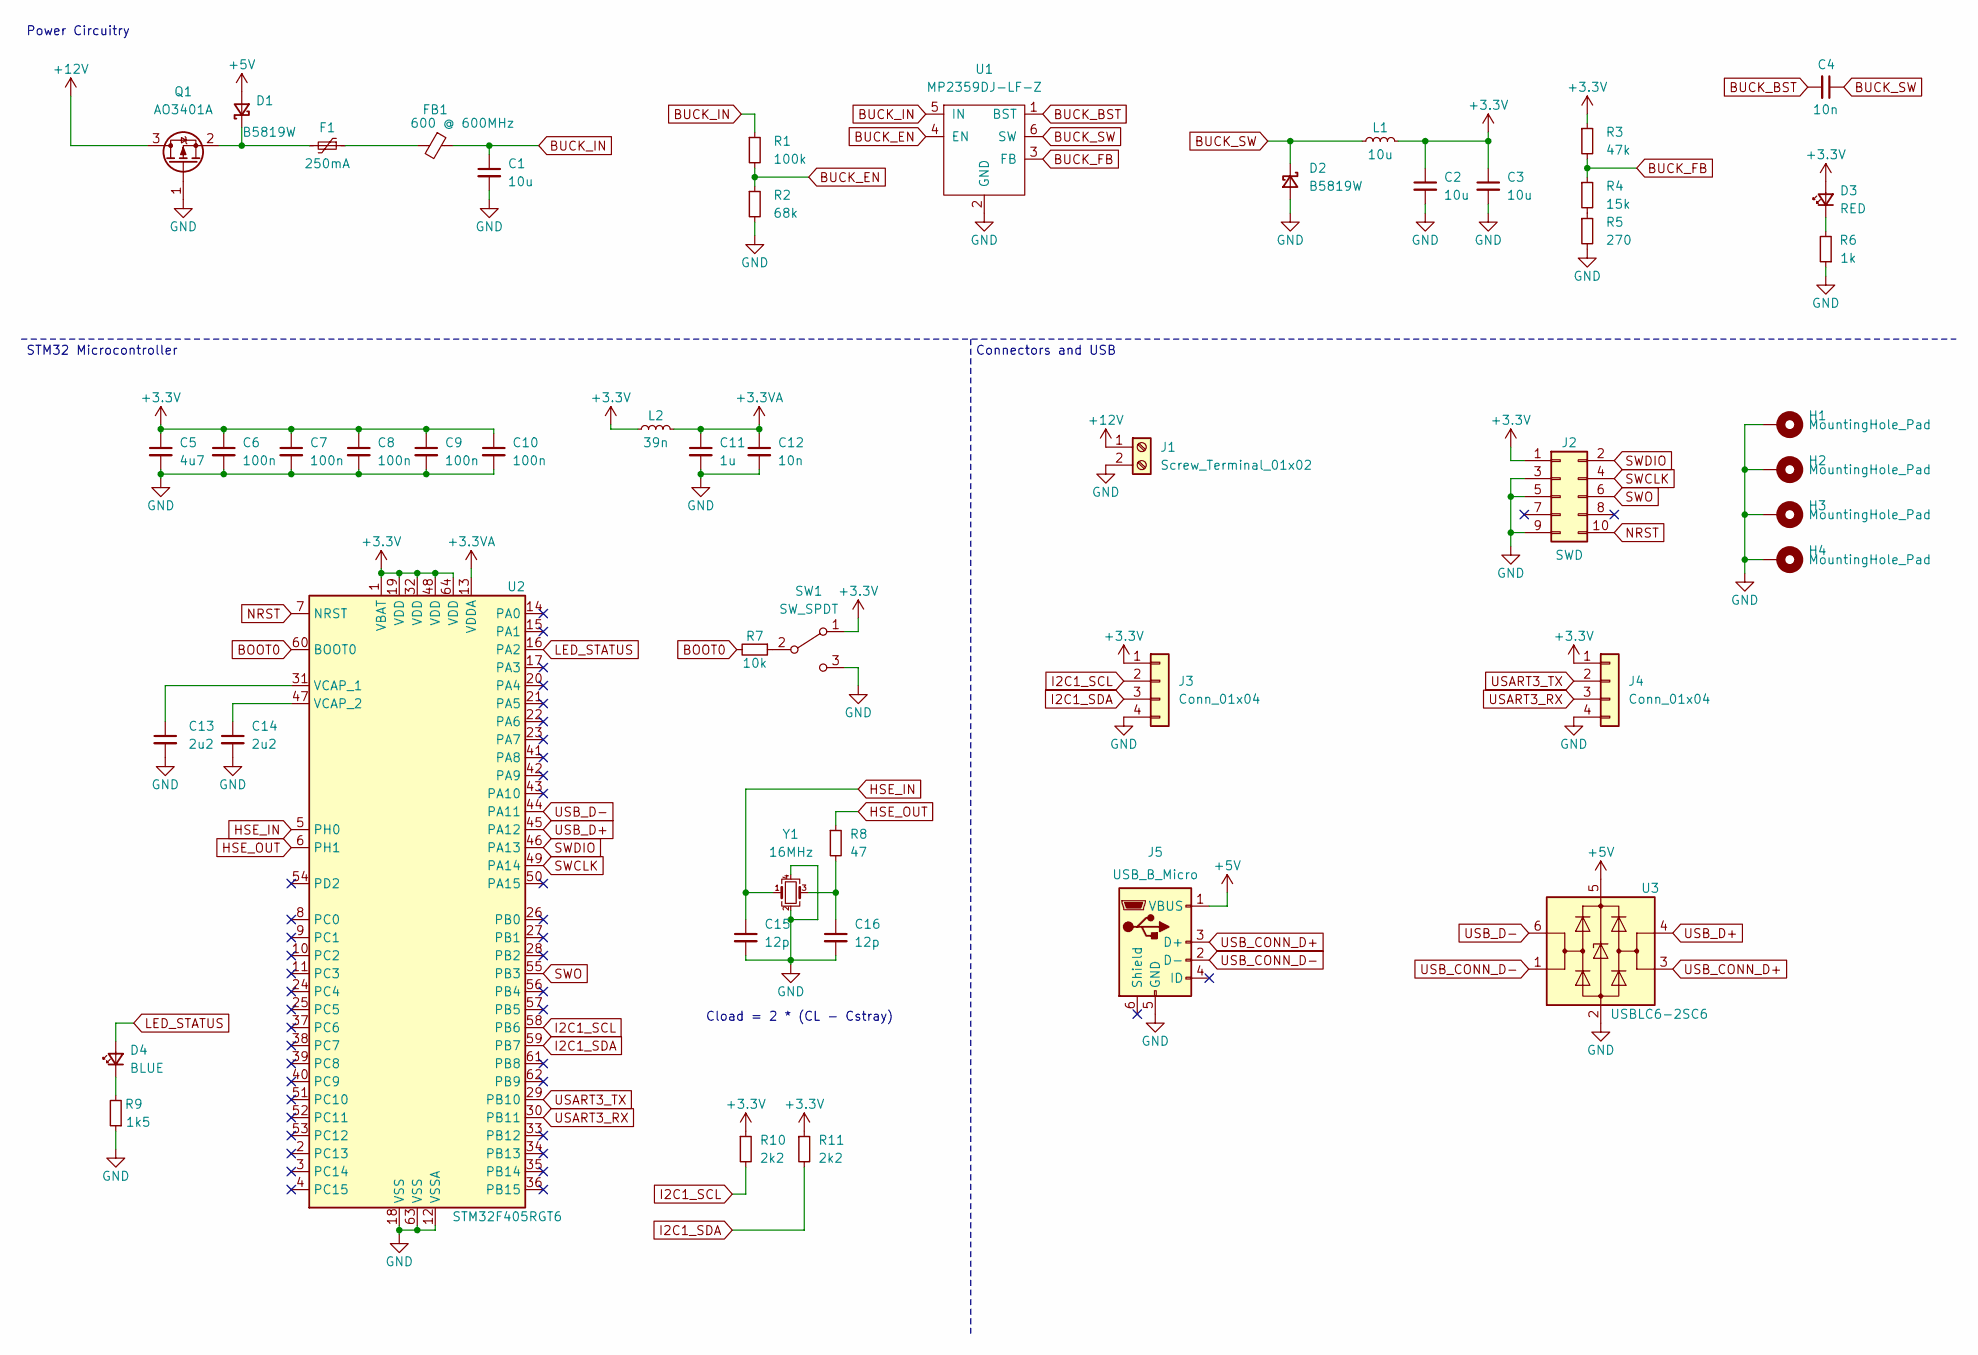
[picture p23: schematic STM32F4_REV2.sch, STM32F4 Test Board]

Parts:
C1, C2, C3: 10u; C_1206_3216Metric; LCSC Part # C13585
C4: 10n; C_0603_1608Metric; LCSC Part # C57112
C5: 4u7; C_0603_1608Metric; LCSC Part # C19666
C6, C7, C8, C9, C10: 100n; C_0402_1005Metric; LCSC Part # C1525
C11: 1u; C_0402_1005Metric; LCSC Part # C52923
C12: 10n; C_0402_1005Metric; LCSC Part # C15195
C13, C14: 2u2; C_0603_1608Metric; LCSC Part # C23630
C15, C16: 12p; C_0402_1005Metric; LCSC Part # C1547
D1, D2: B5819W; D_SOD-123; LCSC Part # C8598
D3: RED; LED_0603_1608Metric; LCSC Part # C2286
D4: BLUE; LED_0603_1608Metric; LCSC Part # C72041
F1: 250mA; Fuse_1206_3216Metric; LCSC Part # C369159
FB1: 600 @ 600MHz; L_0805_2012Metric; LCSC Part # C1017
H1, H2, H3, H4: MountingHole_Pad; MountingHole_4.3mm_M4_Pad_Via
J1: Screw_Terminal_01x02; TerminalBlock_Phoenix_PT-1,5-2-3.5-H_1x02_P3.50mm_Horizontal
J2: SWD; PinHeader_2x05_P1.27mm_Vertical_SMD
J3, J4: Conn_01x04; Molex_PicoBlade_53048-0410_1x04_P1.25mm_Horizontal
J5: USB_B_Micro; USB_MICRO_B_101181930001LF
L1: 10u; L_Sunlord_MWSA0518_5.4x5.2mm; LCSC Part # C139506
L2: 39n; L_0402_1005Metric; LCSC Part # C26443
Q1: AO3401A; SOT-23; LCSC Part # C15127
R1: 100k; R_0603_1608Metric; LCSC Part # C25803
R2: 68k; R_0603_1608Metric; LCSC Part # C23231
R3: 47k; R_0603_1608Metric; LCSC Part # C25819
R4: 15k; R_0603_1608Metric; LCSC Part # C22809
R5: 270; R_0603_1608Metric; LCSC Part # C22966
R6: 1k; R_0603_1608Metric; LCSC Part # C21190
R7: 10k; R_0402_1005Metric; LCSC Part # C25744
R8: 47; R_0402_1005Metric; LCSC Part # C25118
R9: 1k5; R_0603_1608Metric; LCSC Part # C22843
R10, R11: 2k2; R_0402_1005Metric; LCSC Part # C25879
SW1: SW_SPDT; SW_SPDT_PCM12
U1: MP2359DJ-LF-Z; SOT-23-6; LCSC Part # C14259
U2: STM32F405RGT6; LQFP-64_10x10mm_P0.5mm; LCSC Part # C15742
U3: USBLC6-2SC6; SOT-23-6; LCSC Part # C7519
Y1: 16MHz; Crystal_SMD_3225-4Pin_3.2x2.5mm; LCSC Part # C13738

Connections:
+3.3VA: C11.1, C12.1, L2.2, U2.13 (VDDA)
+3V3: C2.1, C3.1, C5.1, C6.1, C7.1, C8.1, C9.1, C10.1, D3.2 (A), J2.1, J3.1, J4.1, L1.2, L2.1, R3.1, R10.1, R11.1, SW1.1 (A), U2.1 (VBAT), U2.19 (VDD), U2.32 (VDD), U2.48 (VDD), U2.64 (VDD)
+5V: D1.2 (A), J5.1 (VBUS), U3.5 (VBUS)
+12V: J1.1, Q1.3 (D)
BOOT0: R7.2, U2.60 (BOOT0)
BUCK_BST: C4.2, U1.1 (BST)
BUCK_EN: R1.2, R2.1, U1.4 (EN)
BUCK_FB: R3.2, R4.1, U1.3 (FB)
BUCK_IN: C1.1, FB1.1, R1.1, U1.5 (IN)
BUCK_SW: C4.1, D2.1 (K), L1.1, U1.6 (SW)
GND: C1.2, C2.2, C3.2, C5.2, C6.2, C7.2, C8.2, C9.2, C10.2, C11.2, C12.2, C13.2, C14.2, C15.2, C16.2, D2.2 (A), H1.1, H2.1, H3.1, H4.1, J1.2, J2.3, J2.5, J2.9, J3.4, J4.4, J5.5 (GND), Q1.1 (G), R2.2, R5.2, R6.1, R9.1, SW1.3 (C), U1.2 (GND), U2.12 (VSSA), U2.18 (VSS), U2.63 (VSS), U3.2 (GND), Y1.2, Y1.4
HSE_IN: C15.1, U2.5 (PH0), Y1.1
HSE_OUT: R8.1, U2.6 (PH1)
I2C1_SCL: J3.2, R10.2, U2.58 (PB6)
I2C1_SDA: J3.3, R11.2, U2.59 (PB7)
LED_STATUS: D4.2 (A), U2.16 (PA2)
NRST: J2.10, U2.7 (NRST)
unnamed: C13.1, U2.31 (VCAP_1)
unnamed: C14.1, U2.47 (VCAP_2)
unnamed: C16.1, R8.2, Y1.3
unnamed: D1.1 (K), F1.2, Q1.2 (S)
unnamed: D3.1 (K), R6.2
unnamed: D4.1 (K), R9.2
unnamed: F1.1, FB1.2
unnamed: R4.2, R5.1
unnamed: R7.1, SW1.2 (B)
SWCLK: J2.4, U2.49 (PA14)
SWDIO: J2.2, U2.46 (PA13)
SWO: J2.6, U2.55 (PB3)
USART3_RX: J4.3, U2.30 (PB11)
USART3_TX: J4.2, U2.29 (PB10)
USB_CONN_D+: J5.3 (D+), U3.3 (I/O2)
USB_CONN_D-: J5.2 (D-), U3.1 (I/O1)
USB_D+: U2.45 (PA12), U3.4 (I/O2)
USB_D-: U2.44 (PA11), U3.6 (I/O1)

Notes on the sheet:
Cload = 2 * (CL - Cstray)
STM32 Microcontroller
Power Circuitry
Connectors and USB

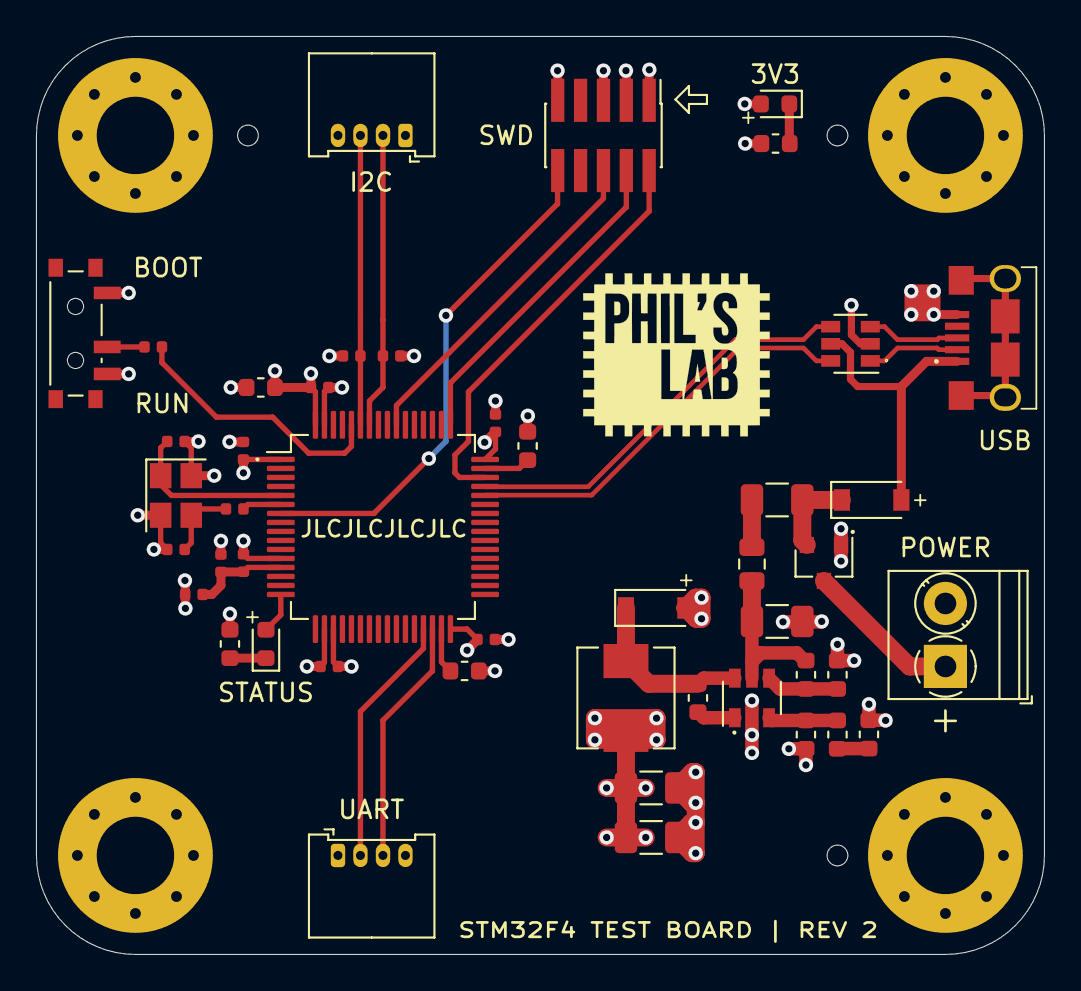
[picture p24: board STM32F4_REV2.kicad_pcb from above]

Board: 4 copper layers, 56.0 x 51.0 mm, 50 parts (0 on the bottom side), 35 nets.

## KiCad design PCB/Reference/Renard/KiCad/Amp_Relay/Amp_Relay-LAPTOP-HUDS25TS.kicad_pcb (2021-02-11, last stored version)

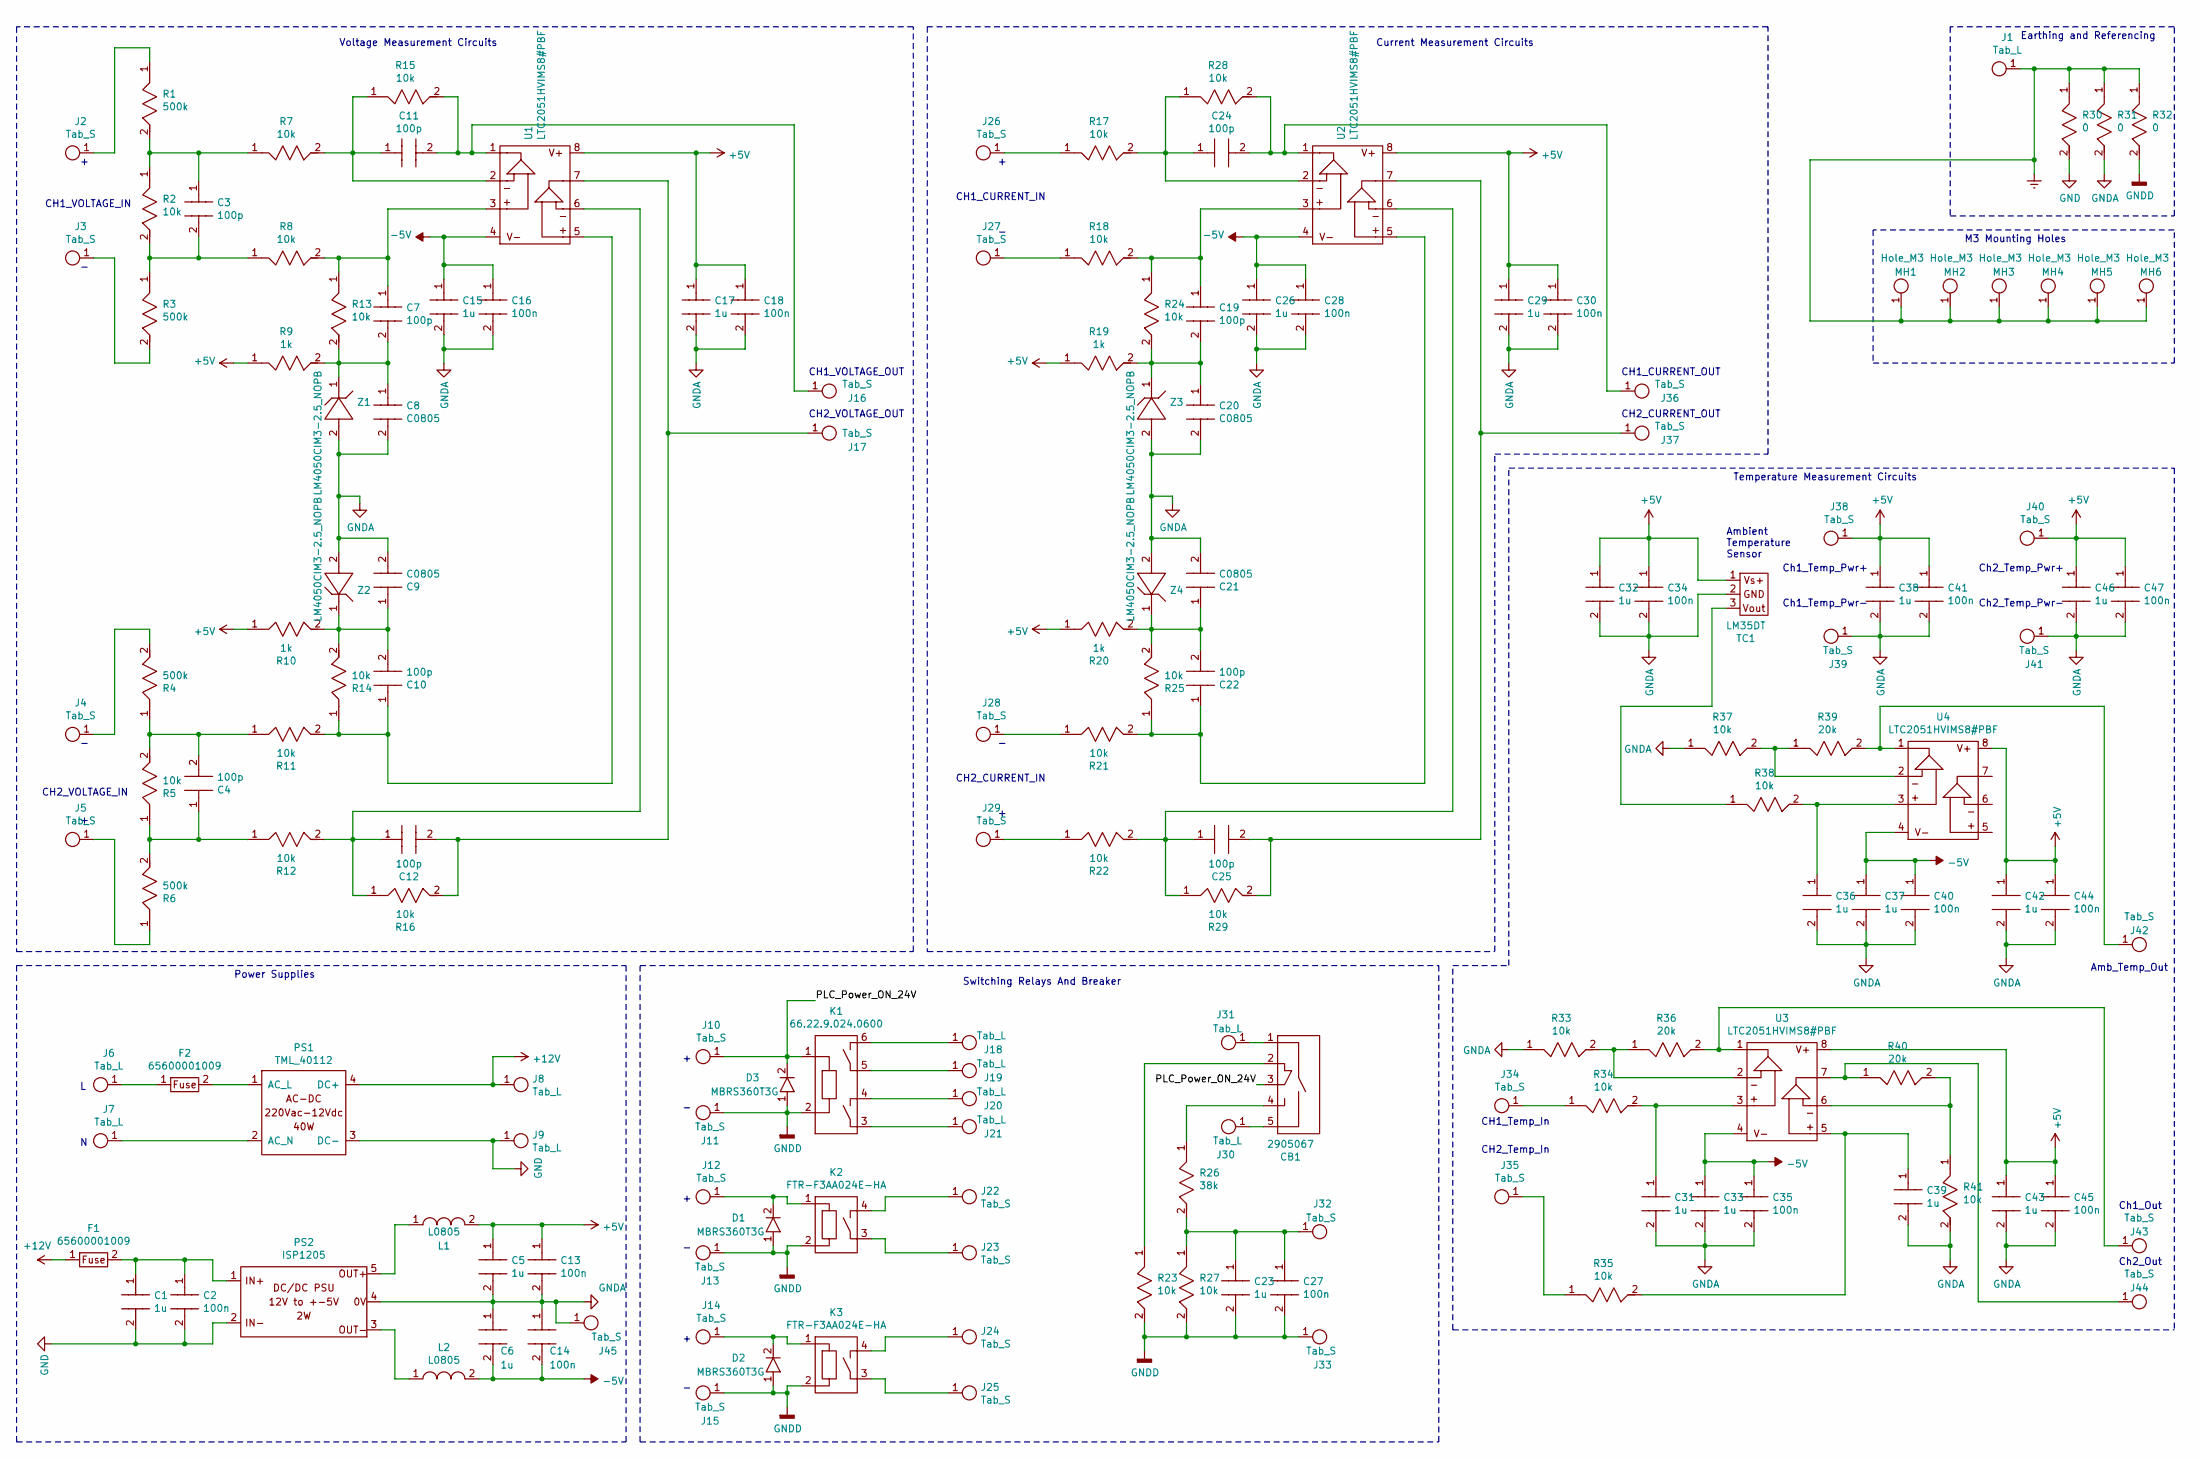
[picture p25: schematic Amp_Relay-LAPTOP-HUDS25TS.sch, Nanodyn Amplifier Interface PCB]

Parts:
C1, C5, C6, C15, C17, C23, C26, C29, C31, C32, C33, C36, C37, C38, C39, C42, C43, C46: 1u; 0805
C2, C13, C14, C16, C18, C27, C28, C30, C34, C35, C40, C41, C44, C45, C47: 100n; 0805
C3, C4, C7, C10, C11, C12, C19, C22, C24, C25: 100p; 0805
C8, C9, C20, C21: C0805; 0805
CB1: 2905067
D1, D2, D3: MBRS360T3G
F1, F2: 65600001009
J1, J6, J7, J8, J9, J18, J19, J20, J21, J30, J31: Tab_L
J2, J3, J4, J5, J10, J11, J12, J13, J14, J15, J16, J17, J22, J23, J24, J25, J26, J27, J28, J29, J32, J33, J34, J35, J36, J37, J38, J39, J40, J41, J42, J43, J44, J45: Tab_S
K1: 66.22.9.024.0600
K2, K3: FTR-F3AA024E-HA
L1, L2: L0805; 0805
MH1, MH2, MH3, MH4, MH5, MH6: Hole_M3; Mounting_Hole_M3
PS1: TML_40112; TML 40112
PS2: ISP1205
R1, R3, R4, R6: 500k; 0805
R2, R5, R7, R8, R11, R12, R13, R14, R15, R16, R17, R18, R21, R22, R23, R24, R25, R27, R28, R29, R33, R34, R35, R37, R38, R41: 10k; 0805
R9, R10, R19, R20: 1k; 0805
R26: 38k; 0805
R30, R31, R32: 0; 0805
R36, R39, R40: 20k; 0805
TC1: LM35DT
U1, U2, U3, U4: LTC2051HVIMS8#PBF
Z1, Z2, Z3, Z4: LM4050CIM3-2.5_NOPB

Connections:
+5V: C5.1, C13.1, C17.1, C18.1, C29.1, C30.1, C32.1, C34.1, C38.1, C41.1, C42.1, C43.1, C44.1, C45.1, C46.1, C47.1, J38.1, J40.1, L1.2, R9.1, R10.1, R19.1, R20.1, TC1.1, U1.8, U2.8, U3.8, U4.8
+12V: F1.1, J8.1, PS1.4 (DC+)
-5V: C6.2, C14.2, C15.1, C16.1, C26.1, C28.1, C33.1, C35.1, C37.1, C40.1, L2.2, U1.4, U2.4, U3.4, U4.4
/PLC_Power_ON_24V: CB1.3, D3.2, J10.1, K1.1
Earth: J1.1, MH1.1, MH2.1, MH3.1, MH4.1, MH5.1, MH6.1, R30.1, R31.1, R32.1
GND: C1.2, C2.2, J9.1, PS1.3 (DC-), PS2.2, R30.2
GNDA: C5.2, C6.1, C8.2, C9.2, C13.2, C14.1, C15.2, C16.2, C17.2, C18.2, C20.2, C21.2, C26.2, C28.2, C29.2, C30.2, C31.2, C32.2, C33.2, C34.2, C35.2, C36.2, C37.2, C38.2, C39.2, C40.2, C41.2, C42.2, C43.2, C44.2, C45.2, C46.2, C47.2, J39.1, J41.1, J45.1, PS2.4, R31.2, R33.1, R37.1, R41.2, TC1.2, Z1.2, Z2.2, Z3.2, Z4.2
GNDD: C23.2, C27.2, D1.1, D2.1, D3.1, J11.1, J13.1, J15.1, J33.1, K1.2, K2.2, K3.2, R23.2, R27.2, R32.2
unnamed: C1.1, C2.1, F1.2, PS2.1
unnamed: C3.1, R1.2, R2.1, R7.1
unnamed: C3.2, R2.2, R3.1, R8.1
unnamed: C4.1, R5.1, R6.2, R12.1
unnamed: C4.2, R4.1, R5.2, R11.1
unnamed: C7.1, R8.2, R13.1, U1.3
unnamed: C7.2, C8.1, R9.2, R13.2, Z1.1
unnamed: C10.1, R11.2, R14.1, U1.5
unnamed: C9.1, C10.2, R10.2, R14.2, Z2.1
unnamed: C11.1, R7.2, R15.1, U1.2
unnamed: C11.2, J16.1, R15.2, U1.1
unnamed: C12.1, R12.2, R16.1, U1.6
unnamed: C12.2, J17.1, R16.2, U1.7
unnamed: C19.1, R18.2, R24.1, U2.3
unnamed: C19.2, C20.1, R19.2, R24.2, Z3.1
unnamed: C21.1, C22.2, R20.2, R25.2, Z4.1
unnamed: C22.1, R21.2, R25.1, U2.5
unnamed: C23.1, C27.1, J32.1, R26.2, R27.1
unnamed: C24.1, R17.2, R28.1, U2.2
unnamed: C24.2, J36.1, R28.2, U2.1
unnamed: C25.1, R22.2, R29.1, U2.6
unnamed: C25.2, J37.1, R29.2, U2.7
unnamed: C31.1, R34.2, U3.3
unnamed: C36.1, R38.2, U4.3
unnamed: C39.1, R35.2, U3.5
unnamed: CB1.1, J31.1
unnamed: CB1.2, R23.1
unnamed: CB1.4, R26.1
unnamed: CB1.5, J30.1
unnamed: D1.2, J12.1, K2.1
unnamed: D2.2, J14.1, K3.1
unnamed: F2.1, J6.1
unnamed: F2.2, PS1.1 (AC_L)
unnamed: J2.1, R1.1
unnamed: J3.1, R3.2
unnamed: J4.1, R4.2
unnamed: J5.1, R6.1
unnamed: J7.1, PS1.2 (AC_N)
unnamed: J18.1, K1.6
unnamed: J19.1, K1.5
unnamed: J20.1, K1.4
unnamed: J21.1, K1.3
unnamed: J22.1, K2.4
unnamed: J23.1, K2.3
unnamed: J24.1, K3.4
unnamed: J25.1, K3.3
unnamed: J26.1, R17.1
unnamed: J27.1, R18.1
unnamed: J28.1, R21.1
unnamed: J29.1, R22.1
unnamed: J34.1, R34.1
unnamed: J35.1, R35.1
unnamed: J42.1, R39.2, U4.1
unnamed: J43.1, R36.2, U3.1
unnamed: J44.1, R40.1, U3.7
unnamed: L1.1, PS2.5
unnamed: L2.1, PS2.3
unnamed: R33.2, R36.1, U3.2
unnamed: R37.2, R39.1, U4.2
unnamed: R38.1, TC1.3
unnamed: R40.2, R41.1, U3.6

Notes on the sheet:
CH2_VOLTAGE_IN
CH1_VOLTAGE_IN
CH1_VOLTAGE_OUT
CH2_VOLTAGE_OUT
CH2_CURRENT_IN
CH1_CURRENT_IN
CH2_CURRENT_OUT
CH1_CURRENT_OUT
Power Supplies
Switching Relays And Breaker
Voltage Measurement Circuits
Current Measurement Circuits
Earthing and Referencing
CH1_Temp_In
CH2_Temp_In
Ch1_Out
Ch2_Out
Ch2_Temp_Pwr+
Ch2_Temp_Pwr-
Amb_Temp_Out
Temperature Measurement Circuits
Ambient Temperature Sensor
Ch1_Temp_Pwr-
Ch1_Temp_Pwr+
M3 Mounting Holes

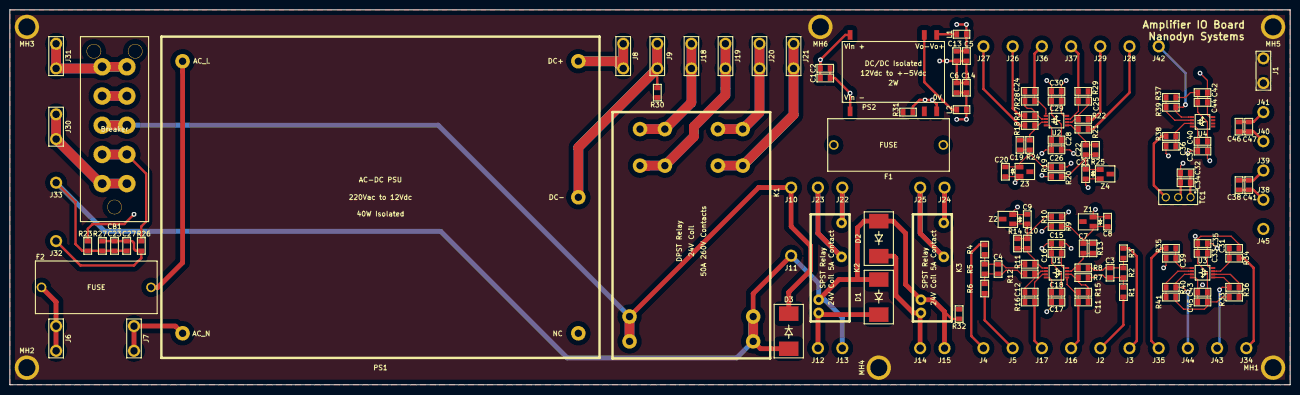
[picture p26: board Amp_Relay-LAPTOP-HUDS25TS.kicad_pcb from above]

Board: 4 copper layers, 263.0 x 77.0 mm, 161 parts (0 on the bottom side), 69 nets.

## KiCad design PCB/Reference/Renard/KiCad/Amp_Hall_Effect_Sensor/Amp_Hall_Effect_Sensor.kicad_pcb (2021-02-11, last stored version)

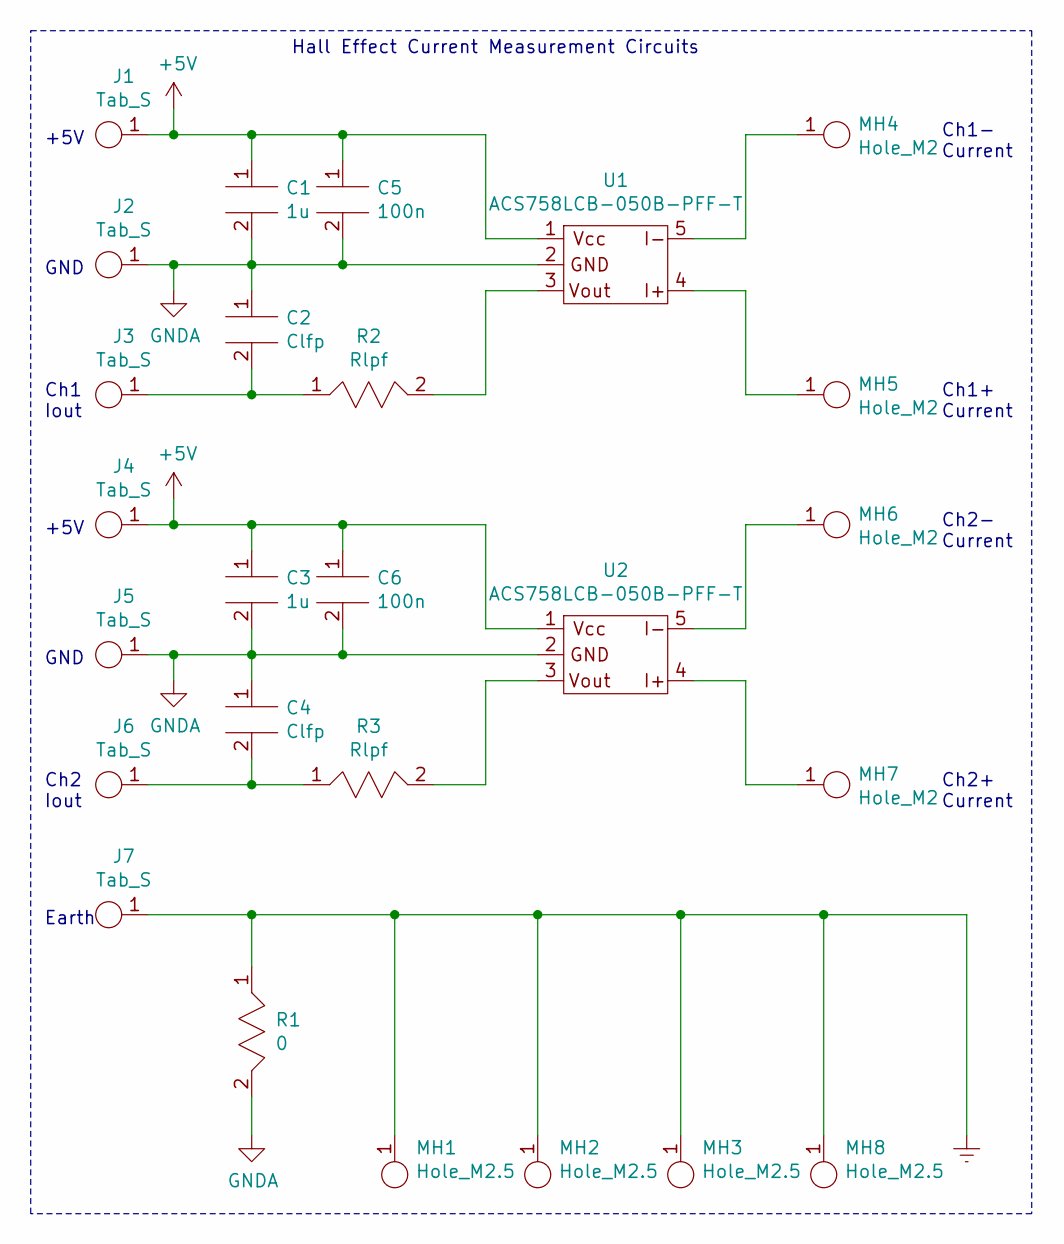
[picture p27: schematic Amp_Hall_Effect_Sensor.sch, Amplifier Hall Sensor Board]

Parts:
C1, C3: 1u; C0805
C2, C4: Clfp; C0805
C5, C6: 100n; C0805
J1, J2, J3, J4, J5, J6, J7: Tab_S
MH1, MH2, MH3, MH8: Hole_M2.5
MH4, MH5, MH6, MH7: Hole_M2
R1: 0; R0805
R2, R3: Rlpf; R0805
U1, U2: ACS758LCB-050B-PFF-T

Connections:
+5V: C1.1, C3.1, C5.1, C6.1, J1.1, J4.1, U1.1, U2.1
Earth: J7.1, MH1.1, MH2.1, MH3.1, MH8.1, R1.1
GNDA: C1.2, C2.1, C3.2, C4.1, C5.2, C6.2, J2.1, J5.1, R1.2, U1.2, U2.2
unnamed: C2.2, J3.1, R2.1
unnamed: C4.2, J6.1, R3.1
unnamed: MH4.1, U1.5
unnamed: MH5.1, U1.4
unnamed: MH6.1, U2.5
unnamed: MH7.1, U2.4
unnamed: R2.2, U1.3
unnamed: R3.2, U2.3

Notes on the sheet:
+5V
GND
Ch1 Iout
Ch2 Iout
Ch1+ Current
Ch1- Current
Ch2- Current
Ch2+ Current
Earth
Hall Effect Current Measurement Circuits

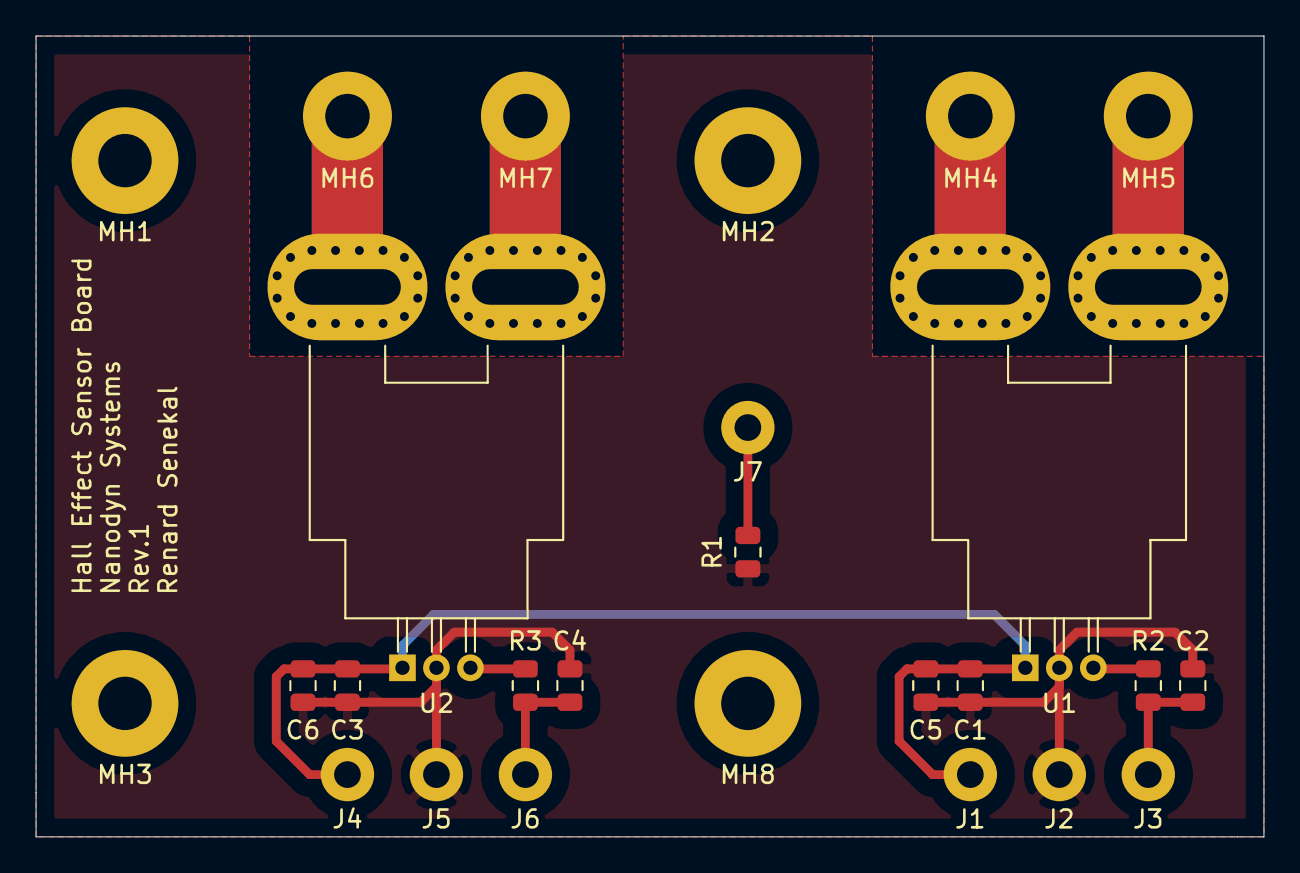
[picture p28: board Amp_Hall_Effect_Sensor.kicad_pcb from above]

Board: 2 copper layers, 69.0 x 45.0 mm, 26 parts (0 on the bottom side), 11 nets.

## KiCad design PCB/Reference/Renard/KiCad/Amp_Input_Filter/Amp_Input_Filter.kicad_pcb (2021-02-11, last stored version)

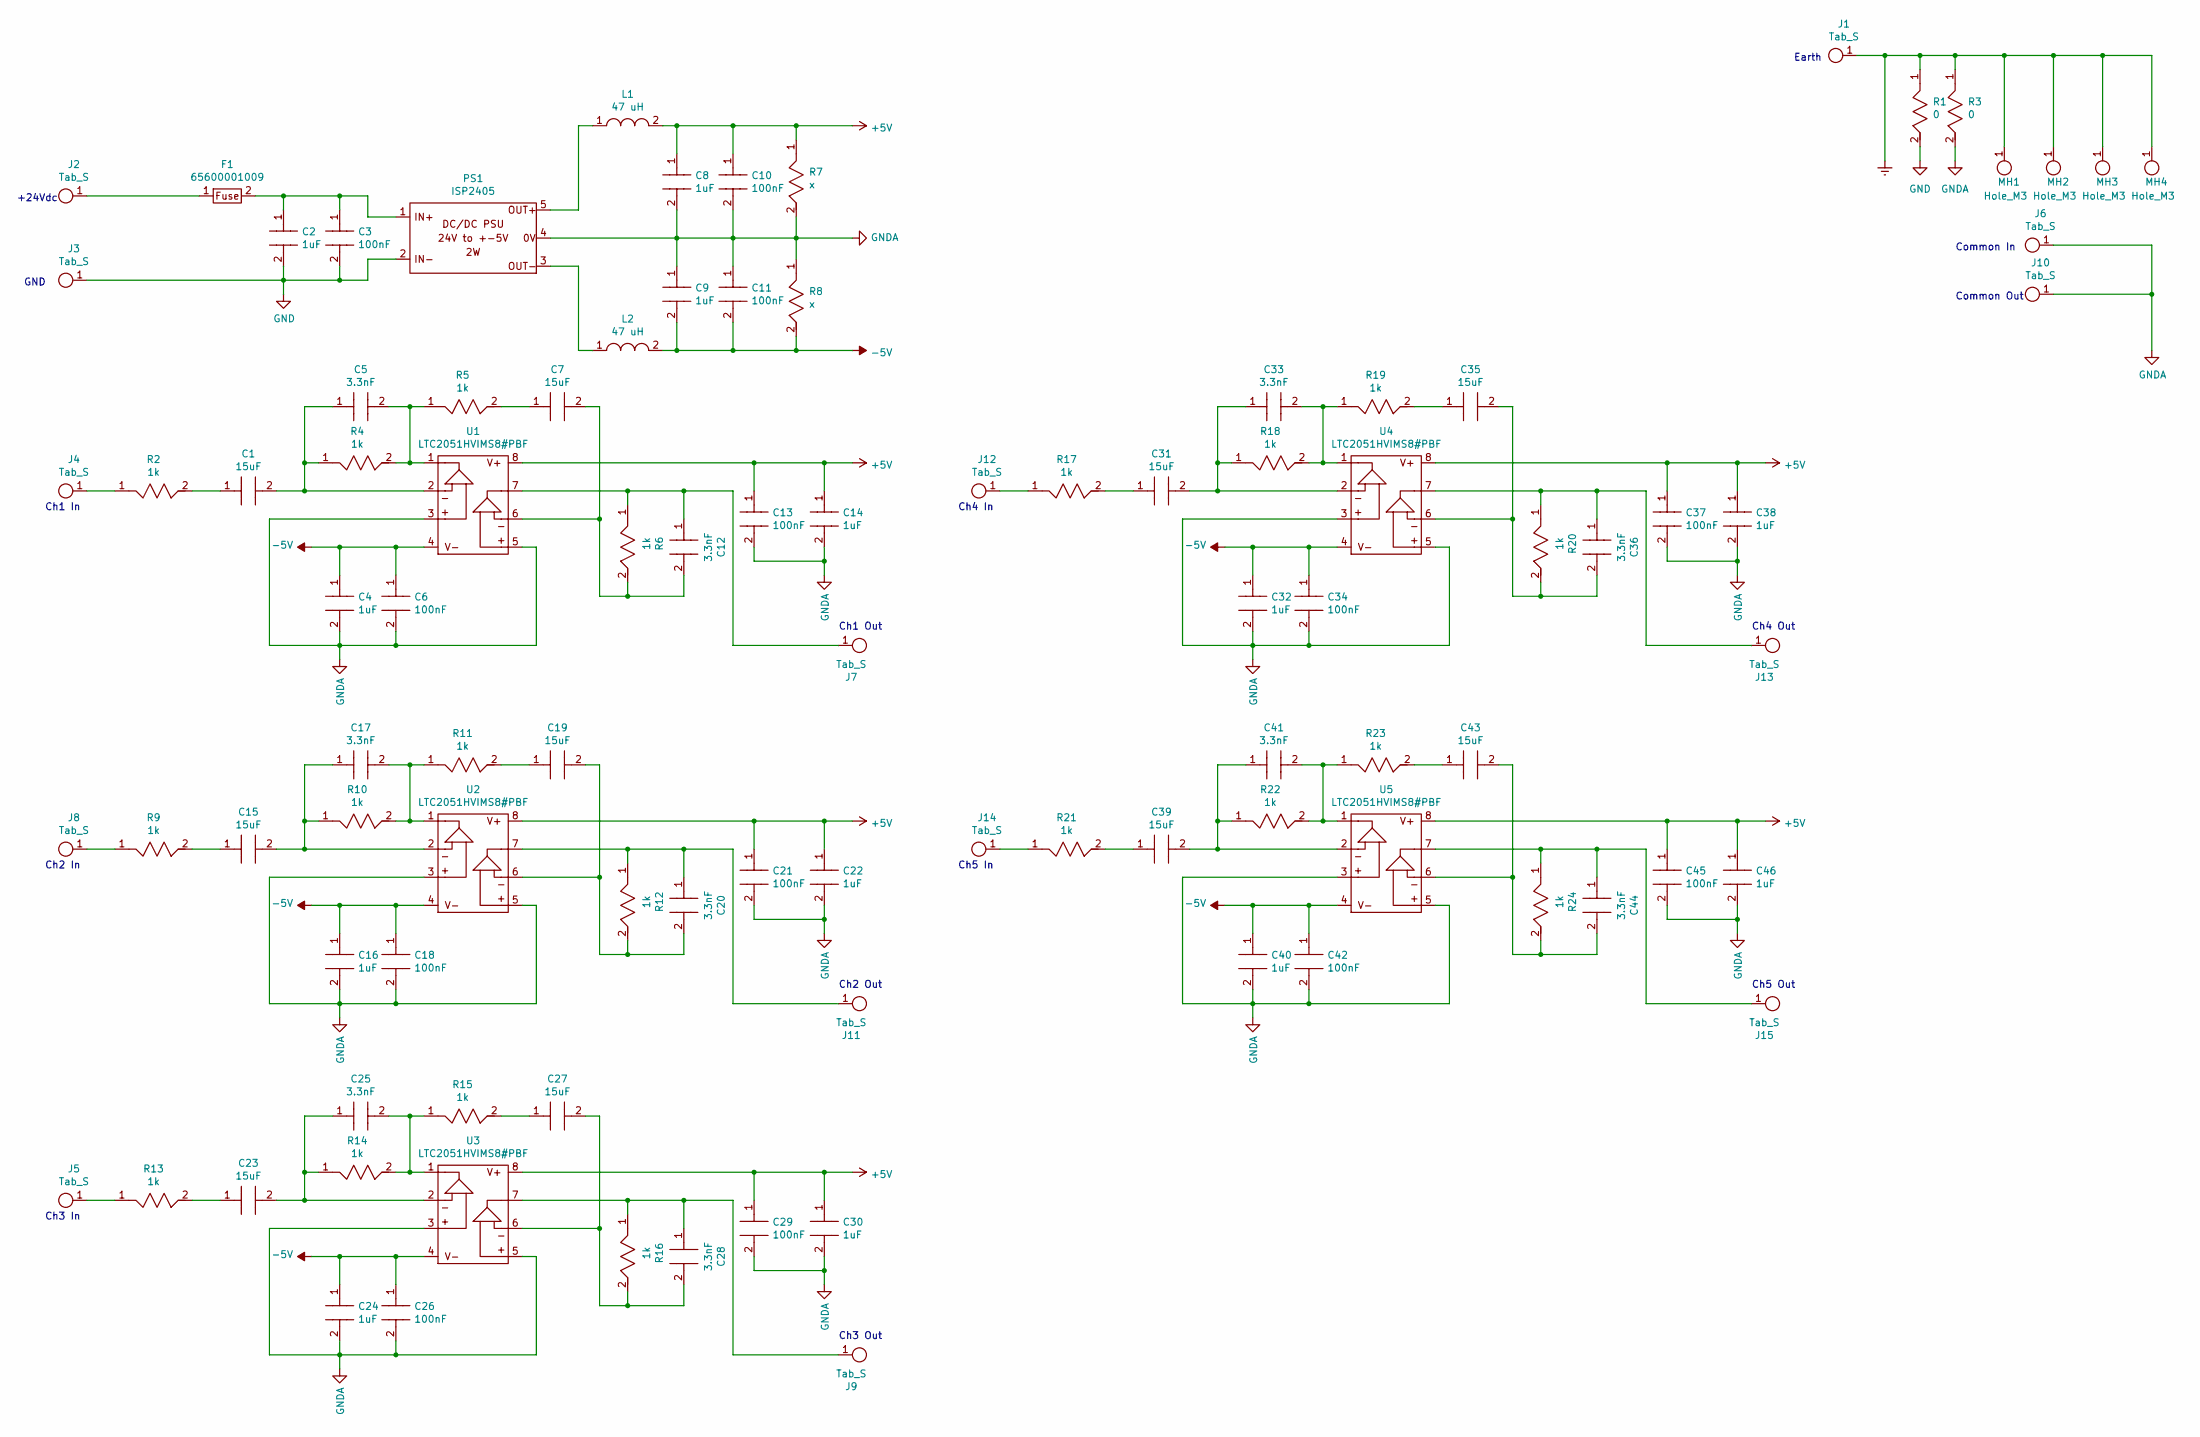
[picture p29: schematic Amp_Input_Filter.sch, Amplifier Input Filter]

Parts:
C1, C7, C15, C19, C23, C27, C31, C35, C39, C43: 15uF; 0805
C2, C4, C8, C9, C14, C16, C22, C24, C30, C32, C38, C40, C46: 1uF; 0805
C3, C6, C10, C11, C13, C18, C21, C26, C29, C34, C37, C42, C45: 100nF; 0805
C5, C12, C17, C20, C25, C28, C33, C36, C41, C44: 3.3nF; 0805
F1: 65600001009
J1, J2, J3, J4, J5, J6, J7, J8, J9, J10, J11, J12, J13, J14, J15: Tab_S
L1, L2: 47 uH; 0805
MH1, MH2, MH3, MH4: Hole_M3; Mounting_Hole_M3
PS1: ISP2405
R1, R3: 0; 0805
R2, R4, R5, R6, R9, R10, R11, R12, R13, R14, R15, R16, R17, R18, R19, R20, R21, R22, R23, R24: 1k; 0805
R7, R8: x; 0805
U1, U2, U3, U4, U5: LTC2051HVIMS8#PBF

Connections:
+5V: C8.1, C10.1, C13.1, C14.1, C21.1, C22.1, C29.1, C30.1, C37.1, C38.1, C45.1, C46.1, L1.2, R7.1, U1.8, U2.8, U3.8, U4.8, U5.8
-5V: C4.1, C6.1, C9.2, C11.2, C16.1, C18.1, C24.1, C26.1, C32.1, C34.1, C40.1, C42.1, L2.2, R8.2, U1.4, U2.4, U3.4, U4.4, U5.4
Earth: J1.1, MH1.1, MH2.1, MH3.1, MH4.1, R1.1, R3.1
GND: C2.2, C3.2, J3.1, PS1.2, R1.2
GNDA: C4.2, C6.2, C8.2, C9.1, C10.2, C11.1, C13.2, C14.2, C16.2, C18.2, C21.2, C22.2, C24.2, C26.2, C29.2, C30.2, C32.2, C34.2, C37.2, C38.2, C40.2, C42.2, C45.2, C46.2, J6.1, J10.1, PS1.4, R3.2, R7.2, R8.1, U1.3, U1.5, U2.3, U2.5, U3.3, U3.5, U4.3, U4.5, U5.3, U5.5
unnamed: C1.1, R2.2
unnamed: C1.2, C5.1, R4.1, U1.2
unnamed: C2.1, C3.1, F1.2, PS1.1
unnamed: C5.2, R4.2, R5.1, U1.1
unnamed: C7.1, R5.2
unnamed: C12.1, J7.1, R6.1, U1.7
unnamed: C7.2, C12.2, R6.2, U1.6
unnamed: C15.1, R9.2
unnamed: C15.2, C17.1, R10.1, U2.2
unnamed: C17.2, R10.2, R11.1, U2.1
unnamed: C19.1, R11.2
unnamed: C19.2, C20.2, R12.2, U2.6
unnamed: C20.1, J11.1, R12.1, U2.7
unnamed: C23.1, R13.2
unnamed: C23.2, C25.1, R14.1, U3.2
unnamed: C25.2, R14.2, R15.1, U3.1
unnamed: C27.1, R15.2
unnamed: C27.2, C28.2, R16.2, U3.6
unnamed: C28.1, J9.1, R16.1, U3.7
unnamed: C31.1, R17.2
unnamed: C31.2, C33.1, R18.1, U4.2
unnamed: C33.2, R18.2, R19.1, U4.1
unnamed: C35.1, R19.2
unnamed: C35.2, C36.2, R20.2, U4.6
unnamed: C36.1, J13.1, R20.1, U4.7
unnamed: C39.1, R21.2
unnamed: C39.2, C41.1, R22.1, U5.2
unnamed: C41.2, R22.2, R23.1, U5.1
unnamed: C43.1, R23.2
unnamed: C43.2, C44.2, R24.2, U5.6
unnamed: C44.1, J15.1, R24.1, U5.7
unnamed: F1.1, J2.1
unnamed: J4.1, R2.1
unnamed: J5.1, R13.1
unnamed: J8.1, R9.1
unnamed: J12.1, R17.1
unnamed: J14.1, R21.1
unnamed: L1.1, PS1.5
unnamed: L2.1, PS1.3

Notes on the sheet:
Ch1 In
Ch1 Out
+24Vdc
GND
Earth
Ch2 In
Ch2 Out
Ch3 In
Ch3 Out
Common In
Common Out
Ch4 In
Ch4 Out
Ch5 Out
Ch5 In

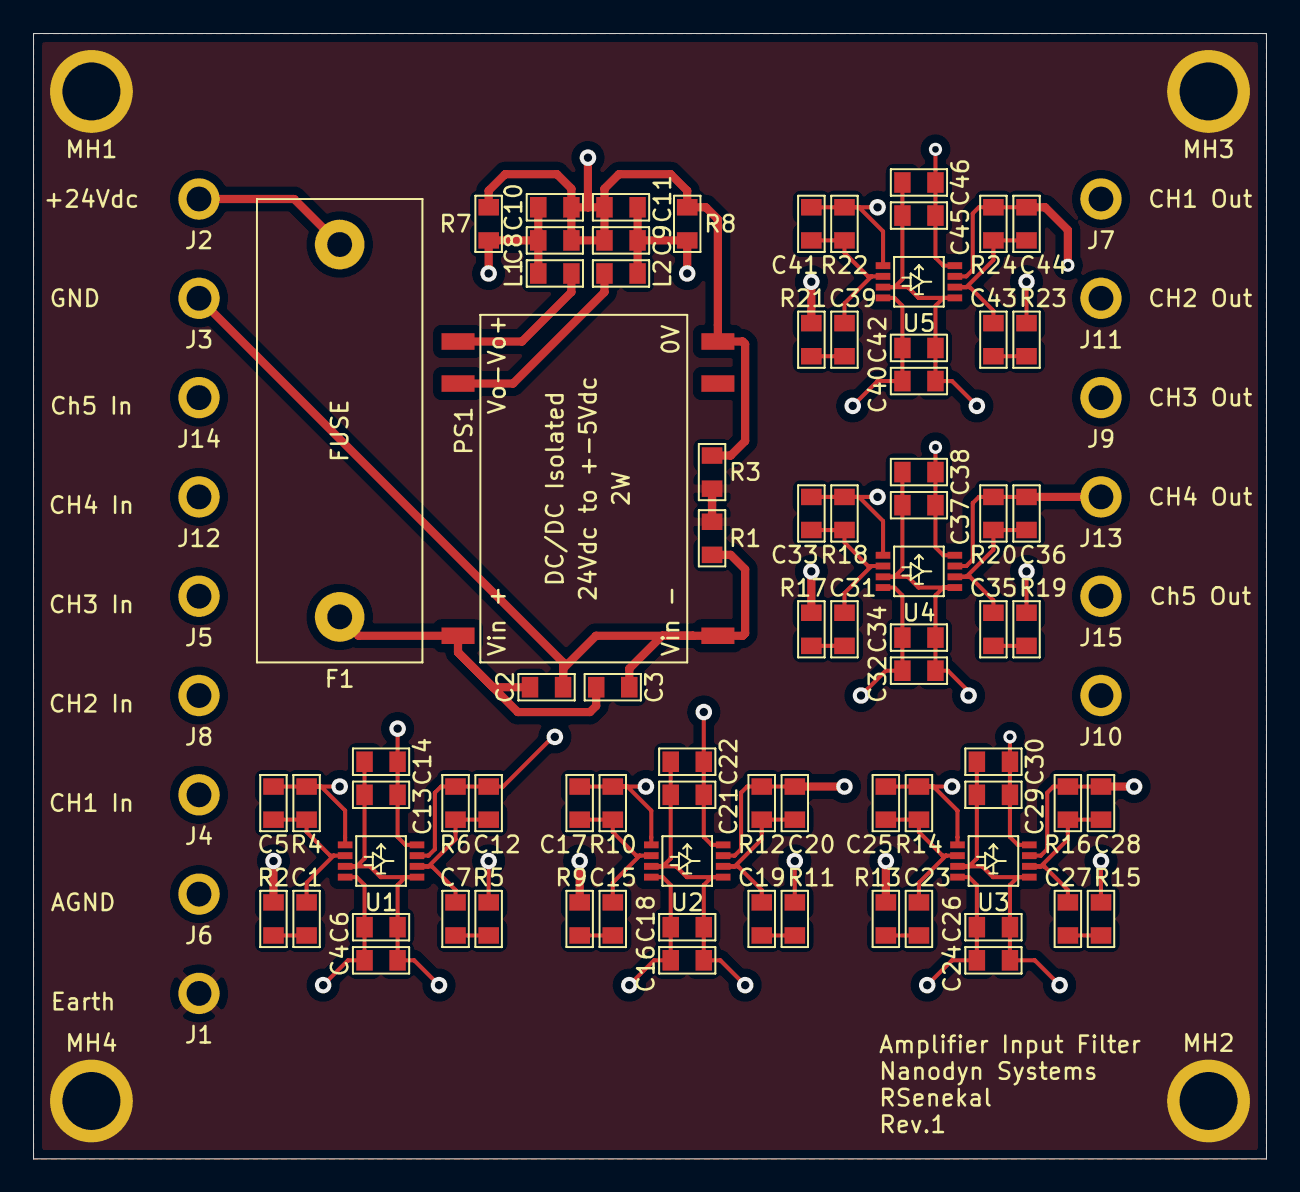
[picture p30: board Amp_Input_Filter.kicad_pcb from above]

Board: 6 copper layers, 74.5 x 68.0 mm, 98 parts (0 on the bottom side), 44 nets.

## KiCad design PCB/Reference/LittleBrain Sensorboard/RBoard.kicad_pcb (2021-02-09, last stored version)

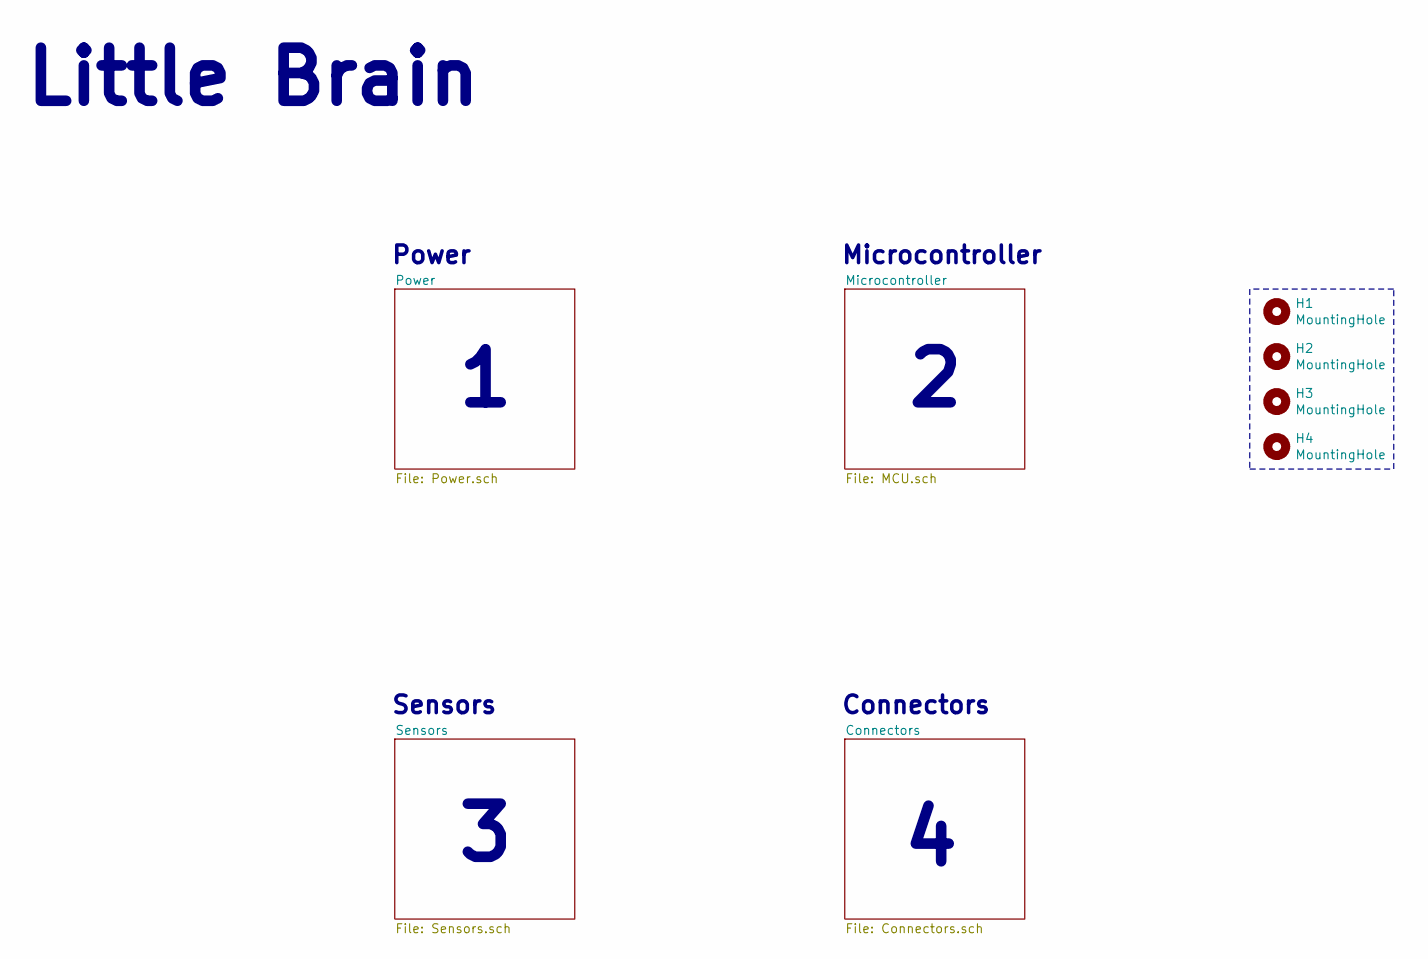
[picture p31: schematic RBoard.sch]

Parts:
H1, H2, H3, H4: MountingHole; MountingHole_3.2mm_M3

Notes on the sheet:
Little Brain
Power
Microcontroller
Sensors
Connectors

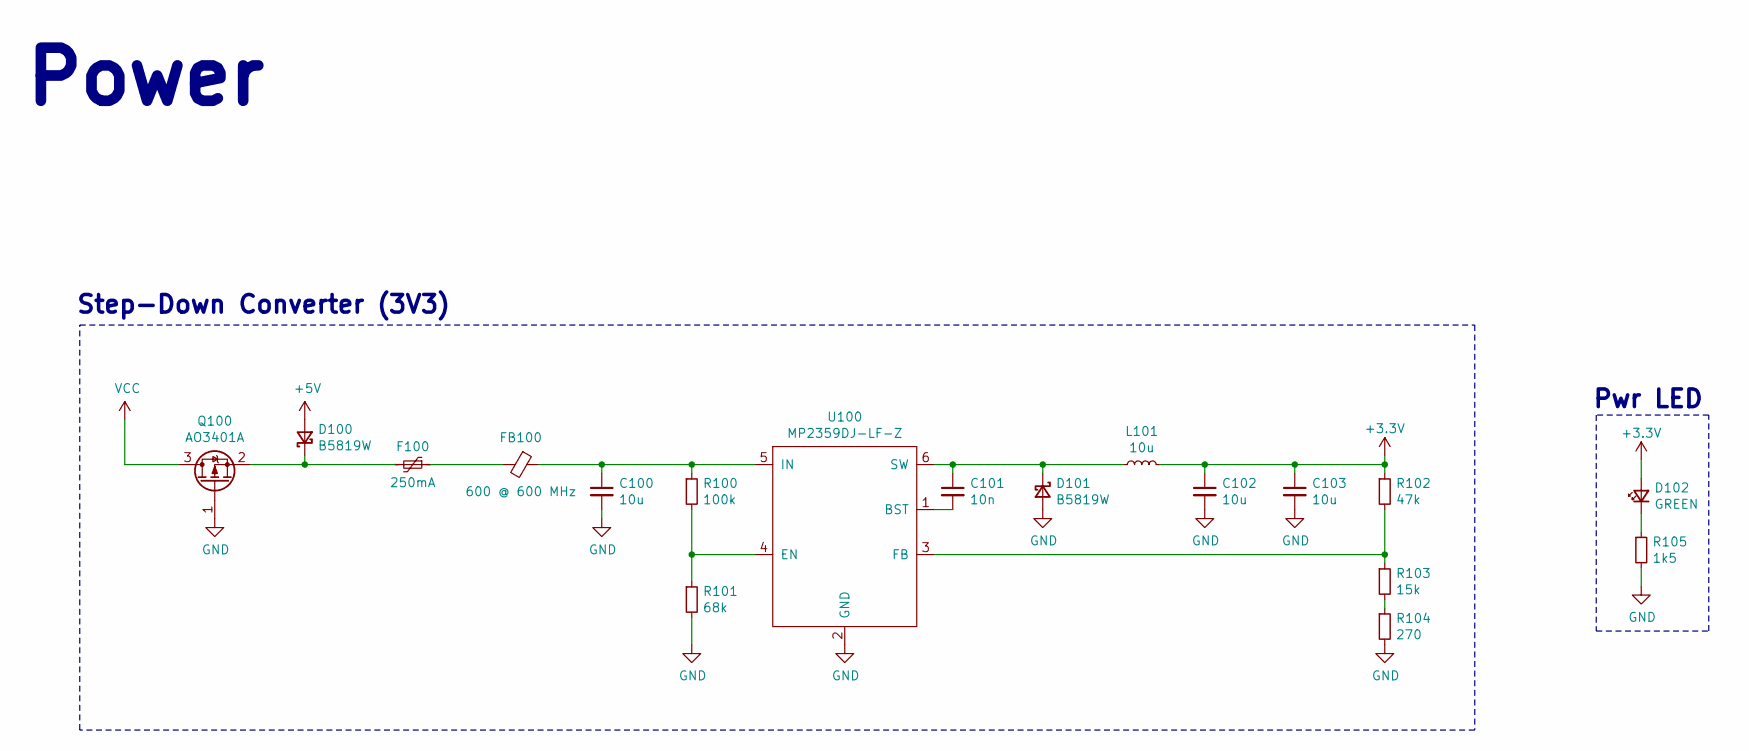
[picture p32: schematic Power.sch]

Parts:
C100, C102, C103: 10u; C_1206_3216Metric; LCSC Part # C13585
C101: 10n; C_0603_1608Metric; LCSC Part # C57112
D100, D101: B5819W; D_SOD-123; LCSC Part # C8598
D102: GREEN; LED_0603_1608Metric; LCSC Part # C72043
F100: 250mA; Fuse_1206_3216Metric; LCSC Part # C70068
FB100: 600 @ 600 MHz; L_0805_2012Metric; LCSC Part # C1017
L101: 10u; L_Sunlord_MWSA0518_5.4x5.2mm; LCSC Part # C139506
Q100: AO3401A; SOT-23; LCSC Part # C15127
R100: 100k; R_0603_1608Metric; LCSC Part # C25803
R101: 68k; R_0603_1608Metric; LCSC Part # C23231
R102: 47k; R_0603_1608Metric; LCSC Part # C25819
R103: 15k; R_0603_1608Metric; LCSC Part # C22809
R104: 270; R_0603_1608Metric; LCSC Part # C22966
R105: 1k5; R_0603_1608Metric; LCSC Part # C22843
U100: MP2359DJ-LF-Z; SOT-23-6; LCSC Part # C14259

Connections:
+3V3: C102.1, C103.1, D102.2 (A), L101.2, R102.1; also elsewhere on the board
+5V: D100.2 (A); also elsewhere on the board
GND: C100.2, C102.2, C103.2, D101.2 (A), Q100.1 (G), R101.2, R104.2, R105.2, U100.2 (GND); also elsewhere on the board
unnamed: C100.1, FB100.1, R100.1, U100.5 (IN)
unnamed: C101.1, D101.1 (K), L101.1, U100.6 (SW)
unnamed: C101.2, U100.1 (BST)
unnamed: D100.1 (K), F100.2, Q100.2 (S)
unnamed: D102.1 (K), R105.1
unnamed: F100.1, FB100.2
unnamed: R100.2, R101.1, U100.4 (EN)
unnamed: R102.2, R103.1, U100.3 (FB)
unnamed: R103.2, R104.1
VCC: Q100.3 (D); also elsewhere on the board

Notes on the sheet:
Power
Step-Down Converter (3V3)
Pwr LED

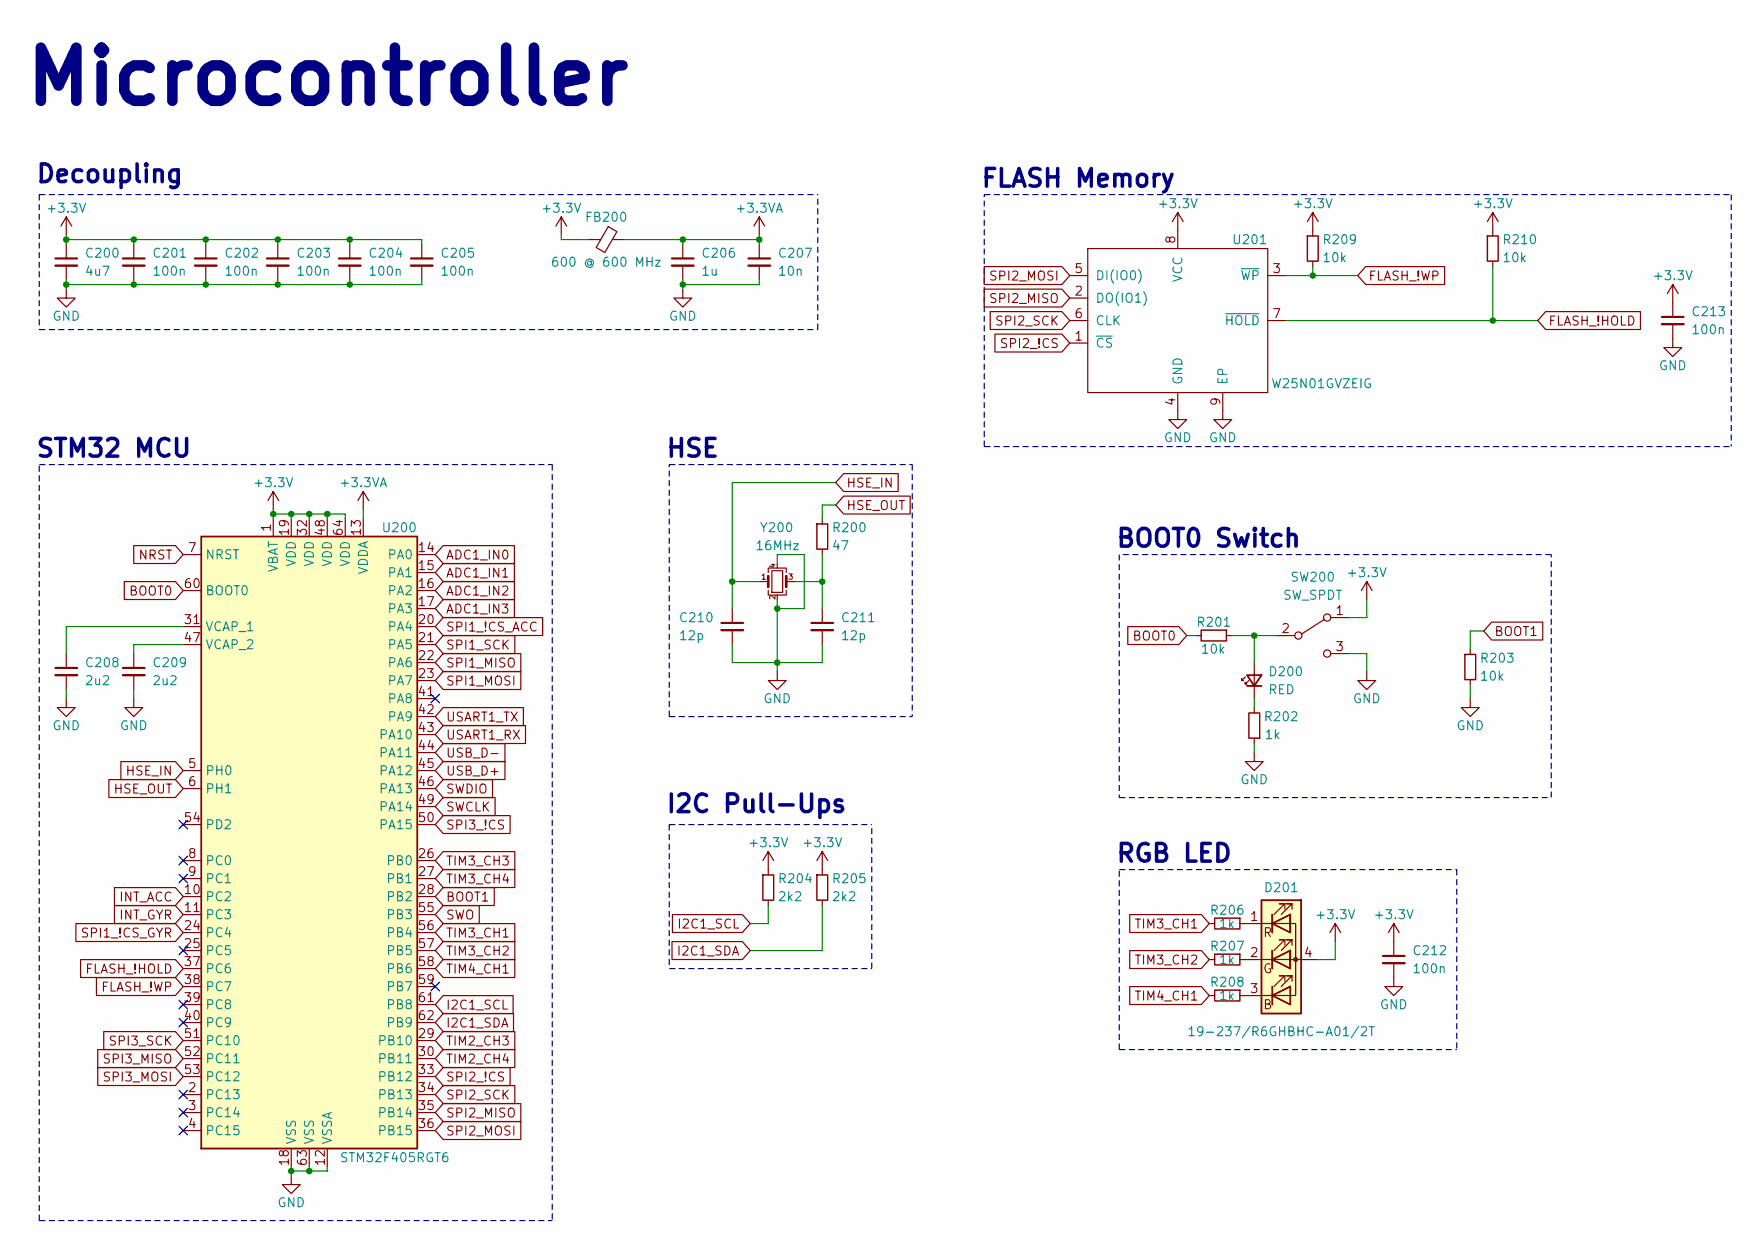
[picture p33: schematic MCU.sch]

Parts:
C200: 4u7; C_0603_1608Metric; LCSC Part # C19666
C201, C202, C203, C204, C205, C212, C213: 100n; C_0402_1005Metric; LCSC Part # C1525
C206: 1u; C_0402_1005Metric; LCSC Part # C52923
C207: 10n; C_0402_1005Metric; LCSC Part # C15195
C208, C209: 2u2; C_0603_1608Metric; LCSC Part # C23630
C210, C211: 12p; C_0402_1005Metric; LCSC Part # C1547
D200: RED; LED_0603_1608Metric; LCSC Part # C2286
D201: 19-237/R6GHBHC-A01/2T; 19-237-R6GHBHC-A01-2T; LCSC Part # C60105
FB200: 600 @ 600 MHz; L_0805_2012Metric; LCSC Part # C1017
R200: 47; R_0402_1005Metric; LCSC Part # C25118
R201, R203, R209, R210: 10k; R_0402_1005Metric; LCSC Part # C25744
R202: 1k; R_0603_1608Metric; LCSC Part # C21190
R204, R205: 2k2; R_0402_1005Metric; LCSC Part # C25879
R206, R207, R208: 1k; R_0402_1005Metric; LCSC Part # C11702
SW200: SW_SPDT; SW_SPDT_PCM12
U200: STM32F405RGT6; LQFP-64_10x10mm_P0.5mm; LCSC Part # C15742
U201: W25N01GVZEIG; LCSC Part # C88868
Y200: 16MHz; Crystal_SMD_3225-4Pin_3.2x2.5mm; LCSC Part # C13738

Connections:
+3.3VA: C206.1, C207.1, FB200.1, U200.13 (VDDA)
+3V3: C200.1, C201.1, C202.1, C203.1, C204.1, C205.1, C212.1, C213.1, D201.4 (A), FB200.2, R204.1, R205.1, R209.1, R210.1, SW200.1 (A), U200.1 (VBAT), U200.19 (VDD), U200.32 (VDD), U200.48 (VDD), U200.64 (VDD), U201.8 (VCC); also elsewhere on the board
ADC1_IN0: U200.14 (PA0); also elsewhere on the board
ADC1_IN1: U200.15 (PA1); also elsewhere on the board
ADC1_IN2: U200.16 (PA2); also elsewhere on the board
ADC1_IN3: U200.17 (PA3); also elsewhere on the board
BOOT0: R201.2, U200.60 (BOOT0)
BOOT1: R203.1, U200.28 (PB2)
FLASH_!HOLD: R210.2, U200.37 (PC6), U201.7 (~HOLD)
FLASH_!WP: R209.2, U200.38 (PC7), U201.3 (~WP)
GND: C200.2, C201.2, C202.2, C203.2, C204.2, C205.2, C206.2, C207.2, C208.2, C209.2, C210.2, C211.2, C212.2, C213.2, R202.1, R203.2, SW200.3 (C), U200.12 (VSSA), U200.18 (VSS), U200.63 (VSS), U201.4 (GND), U201.9 (EP), Y200.2, Y200.4; also elsewhere on the board
HSE_IN: C210.1, U200.5 (PH0), Y200.1
HSE_OUT: R200.1, U200.6 (PH1)
I2C1_SCL: R204.2, U200.61 (PB8); also elsewhere on the board
I2C1_SDA: R205.2, U200.62 (PB9); also elsewhere on the board
INT_ACC: U200.10 (PC2); also elsewhere on the board
INT_GYR: U200.11 (PC3); also elsewhere on the board
NRST: U200.7 (NRST); also elsewhere on the board
unnamed: C208.1, U200.31 (VCAP_1)
unnamed: C209.1, U200.47 (VCAP_2)
unnamed: C211.1, R200.2, Y200.3
unnamed: D200.1 (K), R202.2
unnamed: D200.2 (A), R201.1, SW200.2 (B)
unnamed: D201.1 (RK), R206.1
unnamed: D201.2 (GK), R207.1
unnamed: D201.3 (BK), R208.1
SPI1_!CS_ACC: U200.20 (PA4); also elsewhere on the board
SPI1_!CS_GYR: U200.24 (PC4); also elsewhere on the board
SPI1_MISO: U200.22 (PA6); also elsewhere on the board
SPI1_MOSI: U200.23 (PA7); also elsewhere on the board
SPI1_SCK: U200.21 (PA5); also elsewhere on the board
SPI2_!CS: U200.33 (PB12), U201.1 (~CS)
SPI2_MISO: U200.35 (PB14), U201.2 (DO(IO1))
SPI2_MOSI: U200.36 (PB15), U201.5 (DI(IO0))
SPI2_SCK: U200.34 (PB13), U201.6 (CLK)
SPI3_!CS: U200.50 (PA15); also elsewhere on the board
SPI3_MISO: U200.52 (PC11); also elsewhere on the board
SPI3_MOSI: U200.53 (PC12); also elsewhere on the board
SPI3_SCK: U200.51 (PC10); also elsewhere on the board
SWCLK: U200.49 (PA14); also elsewhere on the board
SWDIO: U200.46 (PA13); also elsewhere on the board
SWO: U200.55 (PB3); also elsewhere on the board
TIM2_CH3: U200.29 (PB10); also elsewhere on the board
TIM2_CH4: U200.30 (PB11); also elsewhere on the board
TIM3_CH1: R206.2, U200.56 (PB4)
TIM3_CH2: R207.2, U200.57 (PB5)
TIM3_CH3: U200.26 (PB0); also elsewhere on the board
TIM3_CH4: U200.27 (PB1); also elsewhere on the board
TIM4_CH1: R208.2, U200.58 (PB6)
USART1_RX: U200.43 (PA10); also elsewhere on the board
USART1_TX: U200.42 (PA9); also elsewhere on the board
USB_D+: U200.45 (PA12); also elsewhere on the board
USB_D-: U200.44 (PA11); also elsewhere on the board

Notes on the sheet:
Microcontroller
STM32 MCU
Decoupling
HSE
FLASH Memory
BOOT0 Switch
RGB LED
I2C Pull-Ups


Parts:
C300, C301, C302, C303: 100n; C_0402_1005Metric; LCSC Part # C1525
U300: BMP280; Bosch_LGA-8_2x2.5mm_P0.65mm_ClockwisePinNumbering; LCSC Part # C233787
U301: BMI088; LCSC Part # C194919

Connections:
+3V3: C300.1, C301.1, C302.1, C303.1, U300.6 (VDDIO), U300.8 (VDD), U301.3 (VDD), U301.11 (VDDIO); also elsewhere on the board
GND: C300.2, C301.2, C302.2, C303.2, U300.1 (GND), U300.7 (GND), U301.2 (NC), U301.4 (GNDA), U301.6 (GNDIO), U301.7 (PS); also elsewhere on the board
INT_ACC: U301.16 (INT1); also elsewhere on the board
INT_GYR: U301.12 (INT3); also elsewhere on the board
SPI1_!CS_ACC: U301.14 (CSB1); also elsewhere on the board
SPI1_!CS_GYR: U301.5 (CSB2); also elsewhere on the board
SPI1_MISO: U301.10 (SDO2), U301.15 (SDO1); also elsewhere on the board
SPI1_MOSI: U301.9 (SDI); also elsewhere on the board
SPI1_SCK: U301.8 (SCK); also elsewhere on the board
SPI3_!CS: U300.2 (CSB); also elsewhere on the board
SPI3_MISO: U300.5 (SDO); also elsewhere on the board
SPI3_MOSI: U300.3 (SDI); also elsewhere on the board
SPI3_SCK: U300.4 (SCK); also elsewhere on the board

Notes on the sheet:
Sensors
Barometric Pressure Sensor
Inertial Measurement Unit


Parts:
C400: 100n; C_0402_1005Metric; LCSC Part # C1525
J400: Conn_01x02; Molex_PicoBlade_53048-0210_1x02_P1.25mm_Horizontal
J401: SWD; PinHeader_2x05_P1.27mm_Vertical_SMD
J402: USB_B_Micro; USB_Micro-B_Wuerth_629105150521
J403, J404, J405, J406, J407, J408: Conn_01x04; Molex_PicoBlade_53048-0410_1x04_P1.25mm_Horizontal
R400, R401, R402, R403, R404, R405, R406, R407, R408, R409, R410, R411, R412, R413, R414, R415: 22; R_0402_1005Metric; LCSC Part # C25092

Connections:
+3V3: J401.1, J403.1, J404.1, J405.1, J406.1, J407.1, J408.1; also elsewhere on the board
+5V: J402.1 (VBUS); also elsewhere on the board
ADC1_IN0: R412.2; also elsewhere on the board
ADC1_IN1: R413.2; also elsewhere on the board
ADC1_IN2: R414.2; also elsewhere on the board
ADC1_IN3: R415.2; also elsewhere on the board
GND: C400.2, J400.2, J401.3, J401.5, J401.9, J402.5 (GND), J403.4, J404.4, J405.4, J406.4, J407.4, J408.4; also elsewhere on the board
I2C1_SCL: R404.2; also elsewhere on the board
I2C1_SDA: R405.2; also elsewhere on the board
NRST: C400.1, R403.1; also elsewhere on the board
unnamed: J401.2, R400.2
unnamed: J401.4, R401.2
unnamed: J401.6, R402.2
unnamed: J401.10, R403.2
unnamed: J403.2, R404.1
unnamed: J403.3, R405.1
unnamed: J404.2, R406.1
unnamed: J404.3, R407.1
unnamed: J405.2, R408.1
unnamed: J405.3, R409.1
unnamed: J406.2, R410.1
unnamed: J406.3, R411.1
unnamed: J407.2, R412.1
unnamed: J407.3, R413.1
unnamed: J408.2, R414.1
unnamed: J408.3, R415.1
SWCLK: R401.1; also elsewhere on the board
SWDIO: R400.1; also elsewhere on the board
SWO: R402.1; also elsewhere on the board
TIM2_CH3: R408.2; also elsewhere on the board
TIM2_CH4: R409.2; also elsewhere on the board
TIM3_CH3: R410.2; also elsewhere on the board
TIM3_CH4: R411.2; also elsewhere on the board
USART1_RX: R407.2; also elsewhere on the board
USART1_TX: R406.2; also elsewhere on the board
USB_D+: J402.3 (D+); also elsewhere on the board
USB_D-: J402.2 (D-); also elsewhere on the board
VCC: J400.1; also elsewhere on the board

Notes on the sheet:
Connectors
USB
Peripherals
Power
SWD


Board: 4 copper layers, 55.0 x 55.0 mm, 86 parts (0 on the bottom side), 80 nets.

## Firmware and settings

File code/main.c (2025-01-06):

/**
  ******************************************************************************
  * @file           : main.c
  * @brief          : Main program body
  * @author         : Nicholas Antoniades
  * @date           : 2020
  ******************************************************************************
  */

#include <string.h>
#include <stdlib.h>

#include "main.h"
#include "stm32_bsp.h"
#include "stm32_lib.h"
#include "uart_message_handler.h"
#include "state_machine.h"

static app_state_t state;

static const app_config_t config = {
    .signal_1 = {
        .timer = &htim2,
        .frequency = 1000,
        .amplitude = 50,
        .offset = 0,
        .channel = TIM_CHANNEL_3
    },
    .signal_2 = {
        .timer = &htim4,
        .frequency = 1000,
        .amplitude = 50,
        .offset = 0,
        .channel = TIM_CHANNEL_4
    },
    .uart = {
        .huart = &huart1,
        .rx_size = 256,
        .tx_size = 256,
        .uart_timeout = 100
    },
    .port_config = {
        .pins_a = (pin_config_t[]) {
            { .pin = 0, .mode = GPIO_MODE_OUTPUT_PP, .pull = GPIO_NOPULL },
        },
        .num_pins_a = 1, 
        .pins_b = (pin_config_t[]) {
            { .pin = 1, .mode = GPIO_MODE_OUTPUT_PP, .pull = GPIO_NOPULL },
        },
        .num_pins_b = 1 
    }
};

static void init_config(app_state_t *state, const app_config_t *config) 
{
    stm32_lib_sig_gen_init(&state->signal_1, &config->signal_1);
    stm32_lib_sig_gen_init(&state->signal_2, &config->signal_2);
    stm32_lib_uart_init(&state->uart_state, &config->uart);
    stm32_lib_port_init(&config->port_config);
}

static void main_loop(app_state_t *state)
{
    while (1)
    {
        stm32_bsp_uart_receive(state->uart_state.huart, 
                               state->uart_state.rx_buff, 
                               state->uart_state.rx_size);

        uint8_t *message = message_handler(&state->uart_state);

        if (message != NULL) state_machine(message, state);
    }
}

int main(void)
{
    stm32_bsp_gpio_init();
    stm32_bsp_dma_init();

    init_config(&state, &config);

    main_loop(&state);
}

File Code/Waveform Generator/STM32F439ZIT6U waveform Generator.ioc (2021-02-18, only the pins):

Mcu.UserName=STM32F439ZITx
PA0/WKUP.Signal=ADCx_IN0
PA1.Signal=ADCx_IN1
PA13.Signal=SYS_JTMS-SWDIO
PA14.Signal=SYS_JTCK-SWCLK
PA2.Signal=USART2_TX
PA3.Signal=USART2_RX
PA4.Signal=COMP_DAC1_group
PA5.Signal=COMP_DAC2_group
PA6.Signal=S_TIM3_CH1
PA8.Signal=S_TIM1_CH1
PA9.Signal=USART1_TX
PB13.GPIO_Label=LED1
PB13.Signal=GPIO_Output
PB14.GPIO_Label=LED2
PB14.Signal=GPIO_Output
PB15.GPIO_Label=LED3
PB15.Signal=GPIO_Output
PB3.Signal=SYS_JTDO-SWO
PB6.Signal=I2C1_SCL
PB7.Signal=USART1_RX
PB9.Signal=I2C1_SDA
PC0.GPIO_Label=MAX485_PWR
PC0.Signal=GPIO_Output
PC1.GPIO_Label=MAX485_DE
PC1.Signal=GPIO_Output
PC6.GPIO_Label=Btn3_Input
PC6.Signal=GPXTI6
PC7.GPIO_Label=Btn2_Input
PC7.Signal=GPXTI7
PC8.GPIO_Label=Btn1_Input
PC8.Signal=GPXTI8
PE5.Signal=S_TIM9_CH1
PH0/OSC_IN.Signal=RCC_OSC_IN
PH1/OSC_OUT.Signal=RCC_OSC_OUT

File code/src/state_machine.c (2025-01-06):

/**
  ******************************************************************************
  * @file           : state_machine.c
  * @brief          : State machine for handling commands
  * @details        : Processes commands to update signal parameters and states
  * @date           : 2020
  * @date           : Nicholas Antoniades
  ******************************************************************************
  */

#include <string.h>
#include <stdlib.h>
#include <math.h>

#include "state_machine.h"
#include "stm32_bsp.h"
#include "stm32_lib.h"

static void state_1(uint8_t rx_buff[], signal_state_t* state);
static void state_2(uint8_t rx_buff[], signal_state_t* state);
static void state_3(uint8_t rx_buff[], signal_state_t* state);
static void state_4(uint8_t rx_buff[], signal_state_t* state);

void state_machine(uint8_t rx_buff[], signal_state_t* state)
{
    uint8_t command = rx_buff[2]; // Extract command from the message
    switch (command) 
    {
        case '1':
            state_1(rx_buff, state);
            break;
        case '2':
            state_2(rx_buff, state);
            break;
        case '3':
            state_3(rx_buff, state);
            break;
        case '4':
            state_4(rx_buff, state);
            break;
        default:
            stm32_bsp_gpio_writepin(LED3_GPIO_Port, LED3_Pin, GPIO_PIN_RESET);
            break;
    }
}

// State 1: Update frequency for Signal 1
static void state_1(uint8_t rx_buff[], signal_state_t* state) 
{
    stm32_bsp_gpio_writepin(LED4_GPIO_Port, LED4_Pin, GPIO_PIN_SET); // Busy
    char frequency_value[6] = {rx_buff[3], rx_buff[4], rx_buff[5], rx_buff[6], rx_buff[7], rx_buff[8]};
    int value_int = atoi(frequency_value);
    if (value_int < state->min_freq) value_int = state->min_freq;
    if (value_int > state->max_freq) value_int = state->max_freq;
    state->freq_signal_1 = value_int;
    set_clock_tim2(state);
}

// State 2: Update frequency for Signal 2
static void state_2(uint8_t rx_buff[], signal_state_t* state) 
{
    stm32_bsp_gpio_writepin(LED4_GPIO_Port, LED4_Pin, GPIO_PIN_SET); // Busy
    char frequency_value[6] = {rx_buff[3], rx_buff[4], rx_buff[5], rx_buff[6], rx_buff[7], rx_buff[8]};
    int value_int = atoi(frequency_value);
    if (value_int < state->min_freq) value_int = state->min_freq;
    if (value_int > state->max_freq) value_int = state->max_freq;
    state->freq_signal_2 = value_int;
    set_clock_tim4(state);
}

// State 3: Update amplitude for Channel 1
static void state_3(uint8_t rx_buff[], signal_state_t* state) 
{
    stm32_bsp_gpio_writepin(LED4_GPIO_Port, LED4_Pin, GPIO_PIN_SET); // Busy
    char amplitude_value[2] = {rx_buff[7], rx_buff[8]};
    int value_int = atoi(amplitude_value);
    if (value_int < state->min_amplitude) value_int = state->min_amplitude;
    if (value_int > state->max_amplitude) value_int = state->max_amplitude;
    state->channel_1_sine_scale = (double)value_int / 100;
    _get_channel_1_sine(state->channel_1_sine_val, state);
}

// State 4: Update amplitude for Channel 2
static void state_4(uint8_t rx_buff[], signal_state_t* state)
{
    stm32_bsp_gpio_writepin(LED4_GPIO_Port, LED4_Pin, GPIO_PIN_SET); // Busy
    char amplitude_value[2] = {rx_buff[7], rx_buff[8]};
    int value_int = atoi(amplitude_value);
    if (value_int < state->min_amplitude) value_int = state->min_amplitude;
    if (value_int > state->max_amplitude) value_int = state->max_amplitude;
    state->channel_2_sine_scale = (double)value_int / 100;
    _get_channel_2_sine(state->channel_2_sine_val, state);
}

void _get_channel_1_sine(double *sine_val, signal_state_t *state) 
{
    if (!sine_val || !state) return;
    *sine_val = state->channel_1_sine_scale * sin(2 * M_PI * state->freq_signal_1 / state->fclock);
}

void _get_channel_2_sine(double *sine_val, signal_state_t *state) 
{
    if (!sine_val || !state) return;
    *sine_val = state->channel_2_sine_scale * sin(2 * M_PI * state->freq_signal_2 / state->fclock);
}

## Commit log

2021-02-09 Working on latest schematic
    [Waveform Generator.sch]
2021-02-09 Working on updating schematic
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2021-02-11 Working on schematic
    [Waveform Generator.sch]
2021-02-11 Updating schematic
    [Battery_3x2_5000mAh.STEP, Battery_6x1_5000mAh.STEP, COMMS.SchDoc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]
2021-02-11 Making more updates
    [Waveform Generator.sch]
2021-02-11 Schematic mostly done
    [Waveform Generator.sch]
2021-02-12 Working on schematic footprints
    [Waveform Generator.sch]
2021-02-12 Almost done with component footprints
    [Waveform Generator.sch]
2021-02-12 Starting PCB layout
    [Waveform Generator.kicad_pcb, Waveform Generator.sch]
2021-02-15 New OP-amps and regulators
    [Waveform Generator.sch]
2021-02-15 Updating op-amps and powersupply
    [Waveform Generator.kicad_pcb, Waveform Generator.sch]
2021-02-16 Making updates to schematic
    [Waveform Generator.kicad_pcb, Waveform Generator.sch]
2021-02-16 Working on next chip
    [Waveform Generator.sch]
2021-02-16 Updating PCB with new micro
2021-02-16 Working on PCB design.
    [Waveform Generator.sch]
2021-02-16 Making progress with Updating the new schematic and footprints
    [Waveform Generator.sch]
2021-02-17 Working on PCB footprint placement
    [Waveform Generator.sch]
2021-02-17 Making progress with PCB layout
    [Waveform Generator.kicad_pcb, Waveform Generator.sch]
2021-02-17 Working on PCB layout
    [Waveform Generator.kicad_pcb, Waveform Generator.sch]
2021-02-17 Updating PCB layout
    [Waveform Generator.kicad_pcb, Waveform Generator.sch]
2021-02-17 Working on PCB design
    [Waveform Generator.kicad_pcb, Waveform Generator.sch]
2021-02-17 Making good progress
    [Waveform Generator.kicad_pcb]
2021-02-17 Finalizing PCB layout
    [Waveform Generator.kicad_pcb, Waveform Generator.sch]
2021-02-17 Made good progress
    [Waveform Generator.kicad_pcb]
2021-02-19 Working on PCB
    [Waveform Generator.sch]
2021-02-19 Making progress
    [Waveform Generator.kicad_pcb]
2021-02-19 Routing power
    [Waveform Generator.kicad_pcb]
2021-02-19 Working on PCB tracks
    [Waveform Generator.kicad_pcb]
2021-02-19 Busy with ground planes
    [Waveform Generator.kicad_pcb]
2021-02-19 Benchmark, looks if the majority of the work is complete
    [Waveform Generator.kicad_pcb]
2021-02-22 Monday morning grind
    [Waveform Generator.kicad_pcb]
2021-02-22 Almost finished with the PCB design
    [Waveform Generator.kicad_pcb]
2021-02-22 Almost done
    [Waveform Generator.kicad_pcb]
2021-02-22 Benchmark, final PCB layout
    [Waveform Generator.kicad_pcb]
2021-02-22 Fixing small things
    [Waveform Generator.kicad_pcb]
2021-02-22 Adding markers to indicator pin 1
    [Waveform Generator.kicad_pcb]
2021-02-22 Logo Applied
    [Waveform Generator.kicad_pcb]
2021-02-22 Stiching vias
    [Waveform Generator.kicad_pcb]
2021-02-22 Working on BOM for JLCPCB
    [Waveform Generator-B_Cu.gbr, Waveform Generator-B_Mask.gbr, Waveform Generator-B_Paste.gbr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]
2021-02-22 working on BOM
    [Waveform Generator.csv]
2021-02-22 Benchmark, Done with BOM, time to place an order
    [Waveform Generator-BOM.csv, Waveform Generator.csv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]
2021-02-22 Benchmark CPL and BOM uploaded.
    [BOM.xlsx, Waveform Generator-BOM.csv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]
2021-02-23 Attempting to submit to JLCPCB
    [BOM.xlsx, Waveform Generator.kicad_pcb, Waveform Generator.sch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]
2021-02-23 Trying to order from JLCPCB
    [BOM.xlsx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]
2021-02-23 Benchmark, Version 1 sent to JLCPCB for manufacture
    [BOM.xlsx, Waveform Generator.sch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]
2021-02-23 Updated files to MCU on PCBs
    [BOM.xlsx, Waveform Generator.kicad_pcb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]
2021-02-23 UART test project now works
2021-02-23 Benchmark, Waveform Generator 2 channel with UART
2021-02-24 Working on Code
    [BOM.xlsx]
2021-02-25 Benchmark, Arbitrary Waveform Generator V1.1
    [Waveform Generator.kicad_pcb, Waveform Generator.sch]
2021-02-25 Revision 1.1
    [Waveform Generator.sch]
2021-02-26 Benchmark, UART, USB, 2 Channel output
    [Waveform Generator.kicad_pcb]
2021-03-01 Bnechamark, UART to serial project
2021-03-03 Working on things
    [STM32F439ZIT6U Waveform Generator Debug.cfg]
2021-03-17 Making adjustments
    [Waveform Generator.sch]
2021-03-18 Working signal generation on the AWG board
2021-03-23 Making progress with the UART protocol. Able to send and receive messages.
2021-03-23 Benchmark, Making good progress with UART comms
2021-03-26 Working hard
    [Aether Light BOM.xlsx]
2021-03-26 Aether Light Basic functioning
    [Aether Light BOM.xlsx]
2021-04-08 Updating schematics and PCB
    [Aether Light BOM.xlsx, BOM.xlsx, STM32F4_REV2.kicad_pcb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]
2021-05-26 Working, possible benchmark
    [BOM.xlsx, Waveform Generator.kicad_pcb]
2021-06-22 Changes made
    [BOM list.xlsx, BOM.xlsx]
2024-10-20 Reorganising files
    [Amp_Hall_Effect_Sensor-B_Cu.gbr, Amp_Hall_Effect_Sensor-B_Mask.gbr, Amp_Hall_Effect_Sensor-B_SilkS.gbr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]
2024-10-20 Clearing up codebase
    [STM32F439ZIT6U Waveform Generator Debug.cfg]
2024-11-08 Major reorgonisation and cleaning
    [STM32F439ZIT6U Waveform Generator Debug.cfg]
2025-01-06 update stm32_bsp.c and .h
